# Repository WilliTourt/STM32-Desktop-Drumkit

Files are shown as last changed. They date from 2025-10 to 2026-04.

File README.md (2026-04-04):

# STM32 Desktop Drumkit

> **Language/语言**: [English](README.md) | [简体中文](README-zh-CN.md)

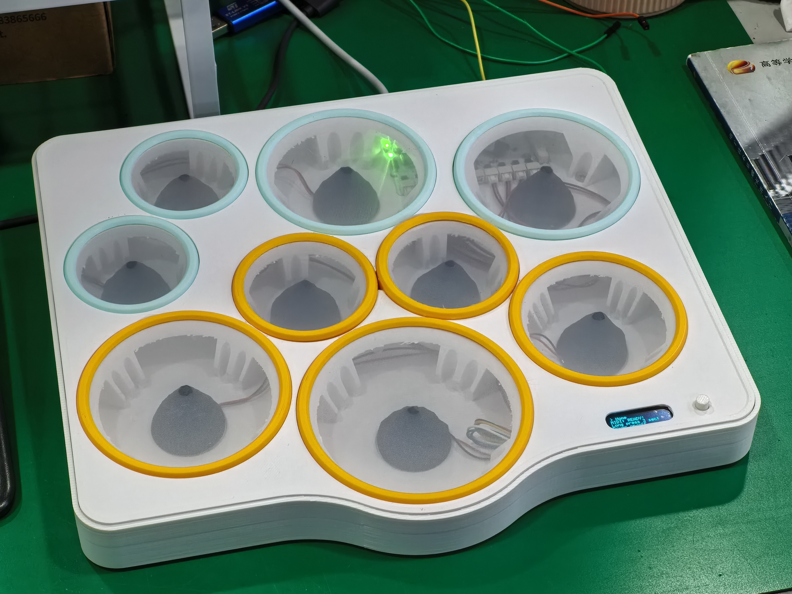
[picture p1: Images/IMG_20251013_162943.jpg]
Drumkit Image

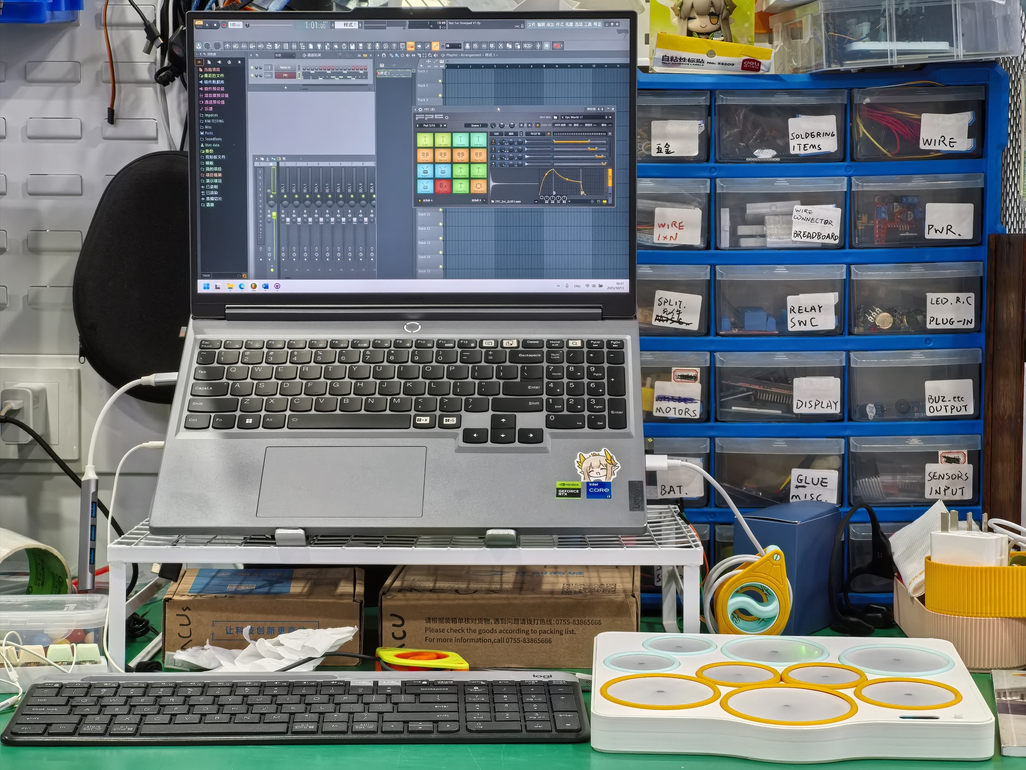
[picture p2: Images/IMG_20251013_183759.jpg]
Usage Example


## Project Overview

*Current Version: v1.0.3*

This project is an upgraded version of my previous ESP32 drum set. Here is its repository link: [ESP32 Desktop Drumkit v0 Prototype](https://github.com/WilliTourt/ESP32-Desktop-Drumkit-v0-Prototype)

STM32 Desktop Drumkit is a multifunctional electronic drumpad system based on STM32F4 microcontroller, supporting high-precision hit detection, native MIDI protocol output, real-time OLED status display, and multilevel menu human-machine interaction. The system includes 10 drum pads, using piezoelectric sensors and multi-channel ADC+DMA to achieve force detection, built-in customizable force curves (linear/logarithmic/exponential), threshold sensitivity adjustment, etc. It supports seamless connection with DAW, sound sources, electronic instruments, etc.

The project includes complete hardware schematics, PCB files, firmware code, debugging documents, assembly guides, etc. This README file provides independent document links for each section, making it easy to access.

Video demo: [Bilibili](https://www.bilibili.com/video/BV1LE4UzUE61/)

---

## Document Index

- [Hardware Design](Docs/hardware.md): Introduce the hardware design related to STM32 Desktop Drumkit, as well as the explanations related to PCB soldering and 3D part printing.
- [Software/Firmware/API Description](Docs/software.md)
- [Assembly Guide](Docs/partsassemble.md): A detailed illustrated guide on how to assemble STM32 Desktop Drumkit.
- [Debugging and Calibration Guide](Docs/howtodebug.md): This document guides you on how to calibrate parameters and conduct tests, etc.
- [FAQ](Docs/faq.md)

---

## Features

- **Multichannel drum pad detection**
- **High-speed ADC sampling and peak detection**
- **Customizable force mapping**
- **Standard MIDI signal transmission**
- **OLED status display and multilevel menu system**

---

## Quick Start

1. Refer to the [Hardware Description](Docs/hardware.md) for component procurement, PCB soldering, hardware circuit inspection and debugging, and 3D case printing.
2. Follow the [Assembly Guide](Docs/partsassemble.md) to complete hardware assembly. (Piezo sensor connection is also included in this step)
3. [Software/Firmware & API Description](Docs/software.md) Check this out, burn the firmware, connect the MIDI interface to the computer or other MIDI devices.
4. After powering on, press and hold the button to turn on the device, the OLED will display the welcome screen and enter the Home page.
5. Follow the [Debugging and Calibration Guide](Docs/howtodebug.md) to complete parameter calibration and testing.

---

## Hardware Description

- **Main Controller**: STM32F405RGT6
- **Piezoelectric Ceramic Disc**: Recommended 27mm, it is advised to use twisted pairs or shielded cables for each signal line.
- **ADC Sampling**: 12-bit precision, multiplexed
- **OLED Display**: 128x32 resolution, I2C interface
- **Others**: LEDs, buzzer, buttons, see the hardware schematic for peripheral interfaces.

---

## Source Code Structure

- `cpp_main.cpp/h` : Main program entry, main loop, Pad/MIDI/UI initialization and scheduling
- `pad.cpp/h` : Drum pad detection, force mapping, and parameter management
- `midi.cpp/h` : MIDI communication protocol, signal transmission, automatic Note Off, connection detection
- `oled.cpp/h` : OLED screen driver, text/variable/graphic display
- `OneButtonTiny.cpp/h` : Multimode input detection for a single button (single click/double click/long press/multi-click)
- `ui.cpp/h` : User interface and menu system management

---

## Changelog (Since 2025.10.14)

- [x] Complete documentation
- [x] Add config.h for parameter customization
- [x] Optimized knock recognition
- [x] Complete DebugLog feature

Below are undone features. Due to my limited time, this project is considered completed and will not be updated later

- [ ] Optimize UI interface
- [ ] Complete LED/BUZZER functionality
- [ ] Add PadTest feature
- [ ] Add PadSettings fine-tuning parameters
- [ ] SSTK sensor support
- [ ] Add 3D file of the base plate bracket
...

---

## Acknowledgments

- Thanks to [MoraiYanKele](https://github.com/MoraiYanKele) for providing his OLED multilevel menu library.
- Thanks to Matthias Hertel's Arduino Onebutton library, part of its functionality has been ported to this project.
- This project was initially inspired by [Victor2805/Homemade-electronic-drum-kit-with-arduino](https://github.com/Victor2805/Homemade-electronic-drum-kit-with-arduino).
- Thanks to my cousin who loves percussion instruments and is experienced with DAW, he provided many modification suggestions for the prototype @[Woodbreeze](https://github.com/WoodBreeze) ;)
- Thanks to all the authors of the open-source libraries and the DIY community for sharing their experiences.

---

**WilliTourt / 2025.10 V1 Release**

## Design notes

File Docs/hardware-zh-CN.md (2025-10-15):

# STM32 Desktop Drumkit - 硬件说明

> 此文档将会介绍STM32 Desktop Drumkit的硬件设计相关，以及PCB焊接和3D件打印相关说明。

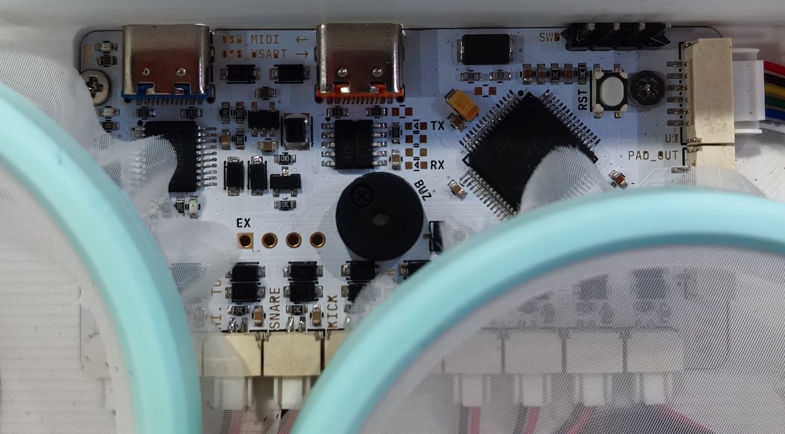
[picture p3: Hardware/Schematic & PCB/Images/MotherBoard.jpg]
主板PCB图

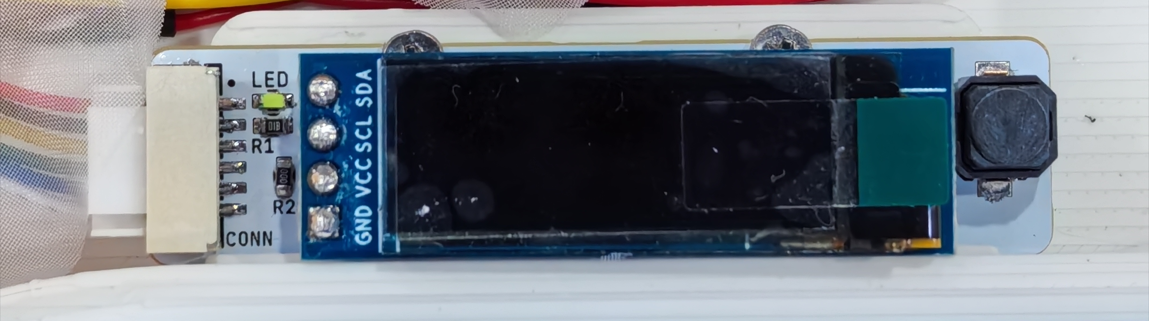
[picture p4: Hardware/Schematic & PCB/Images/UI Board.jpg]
UI小板PCB图

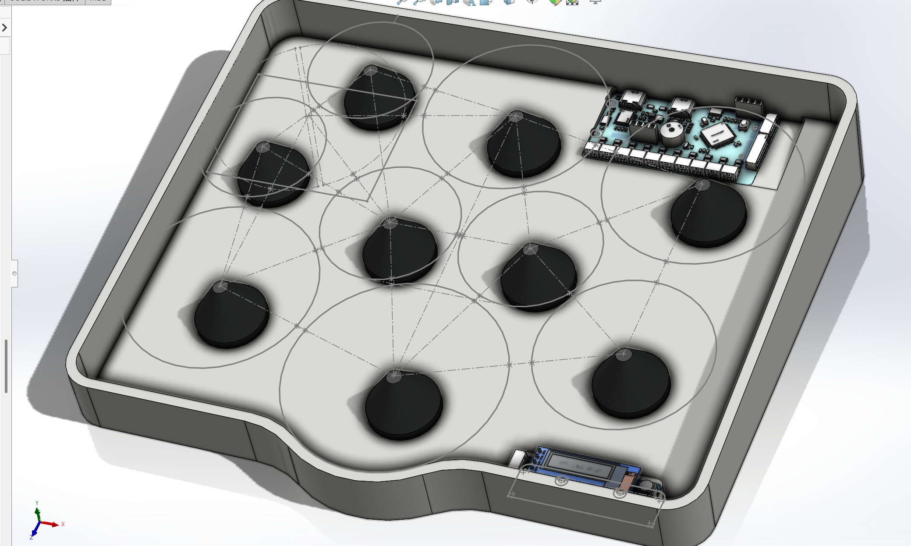
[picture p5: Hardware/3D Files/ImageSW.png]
3D外壳图


## PCB元器件清单

PCB所需元器件在[BOM文件夹](../Hardware/Schematic%20&%20PCB/PCB%20BOM)的表格中均已列出。PCB的设计文件和Gerber也在[原理图/PCB文件夹](../Hardware/Schematic%20&%20PCB)中。PCB包括两部分：主板和用户交互小板。

## PCB原理图说明

### 主板原理图
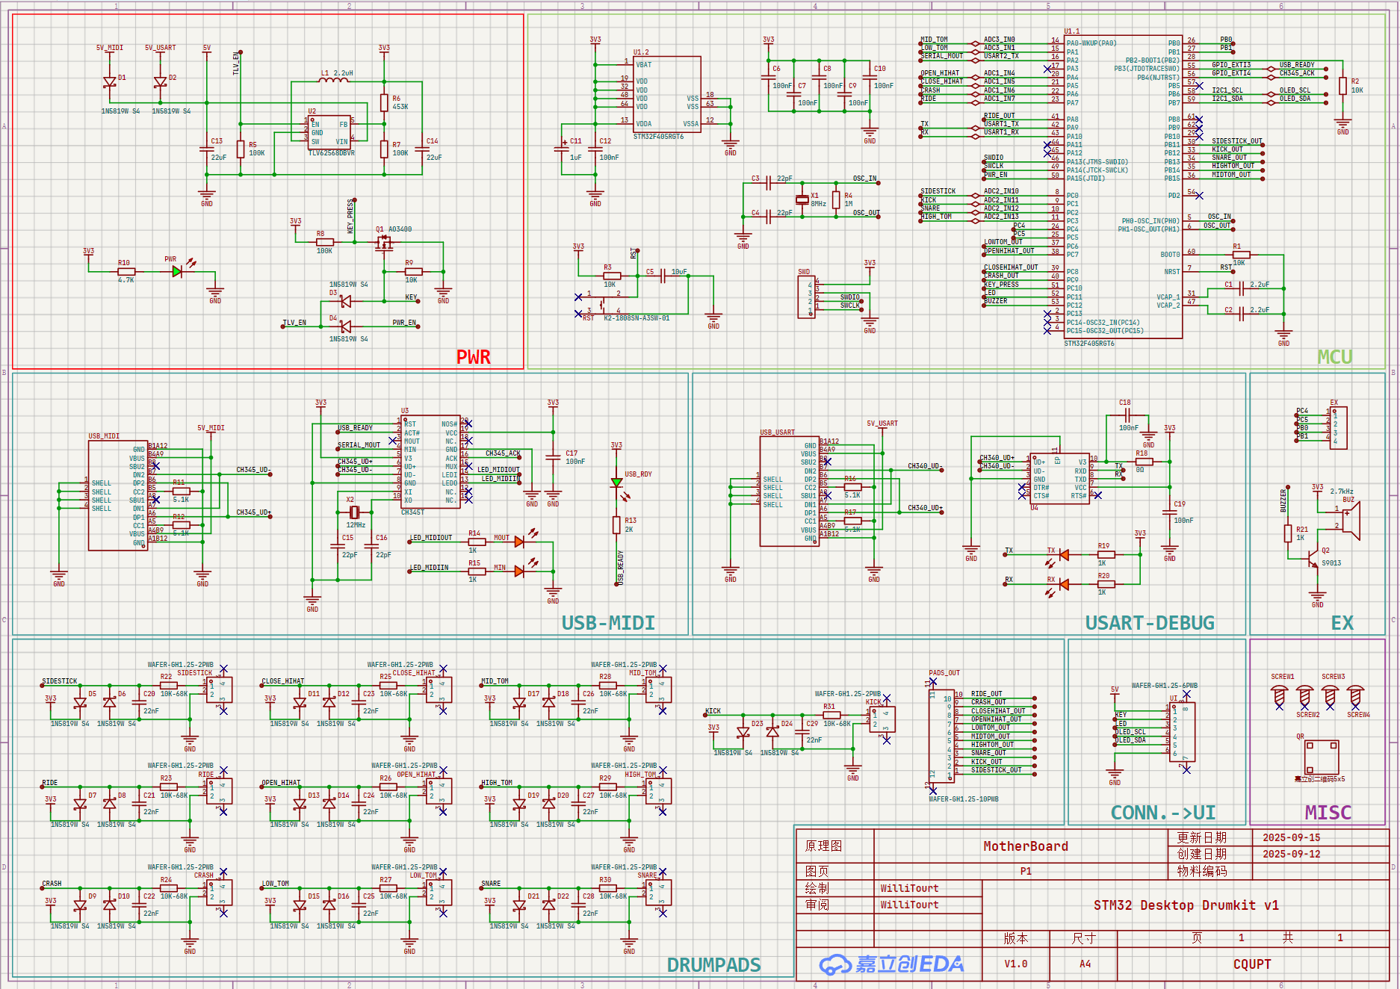
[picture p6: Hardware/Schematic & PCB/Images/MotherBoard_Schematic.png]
主板原理图


主板主要包括以下部分：
- MCU
- 电源
- 通信接口
- 压电片信号处理

信号输入输出流程：
1. 10路信号处理电路将外部压电片原信号进行偏置和限幅
2. 处理后的信号连接到MCU的ADC
3. MCU发送MIDI信息到CH345T USB-MIDI芯片
4. 发送调试信息到CH340K
5. 控制板载蜂鸣器
6. 通过6pin GH1.25接口：
   - 发送I2C数据到OLED
   - 控制LED
   - 接收按键输入

### 用户交互小板原理图
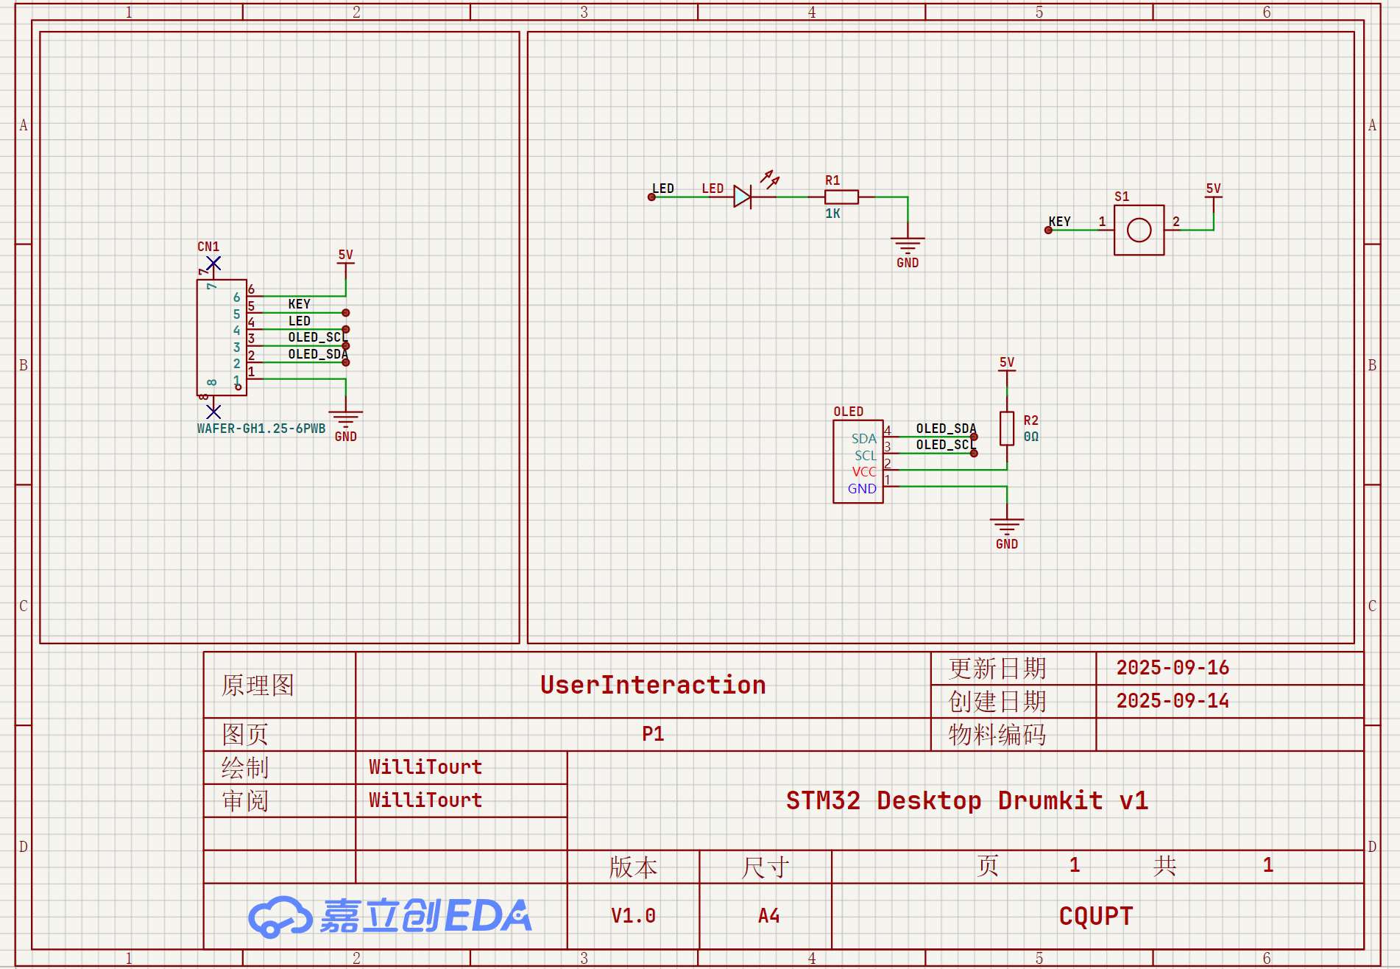
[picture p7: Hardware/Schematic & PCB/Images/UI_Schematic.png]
用户交互小板原理图


- 通过6pin接口接收来自MCU的数据
- MCU同时检测按键信号

## PCB布局

### 主板PCB布局
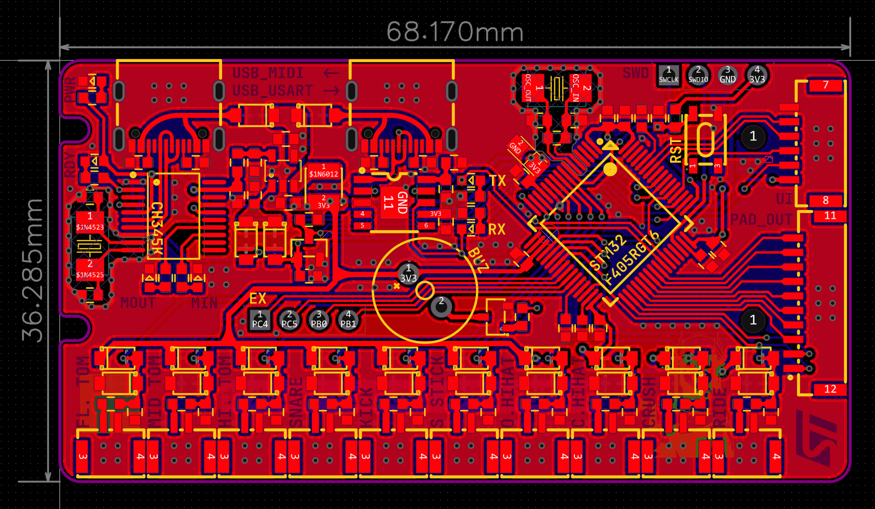
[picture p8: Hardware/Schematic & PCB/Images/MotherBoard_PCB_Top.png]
主板PCB布局


- 上方：三个接口
  - MIDI
  - UART_DEBUG
  - SWD
- 右侧：
  - 6pin用于连接UI小板的接口
  - 10pin输出控制接口
- 下方：10路独立的压电片信号处理电路
- 中部：
  - 电源选择电路
  - 开关机电路
  - DCDC降压器
  - MCU
  - 4个额外的IO

板上线路和STM32CubeMX配置相对应。使用CubeMX查看外设和引脚配置。

## PCB焊接注意事项

### 主板焊接注意事项
1. TLV62568的反馈电阻(100k/453k)切勿相互焊反
2. CH340K部分：
   - R18和C19焊接时请二选一
   - 推荐仅焊接R18以向V3引脚供3.3v电源（详细解释见CH340K数据手册）
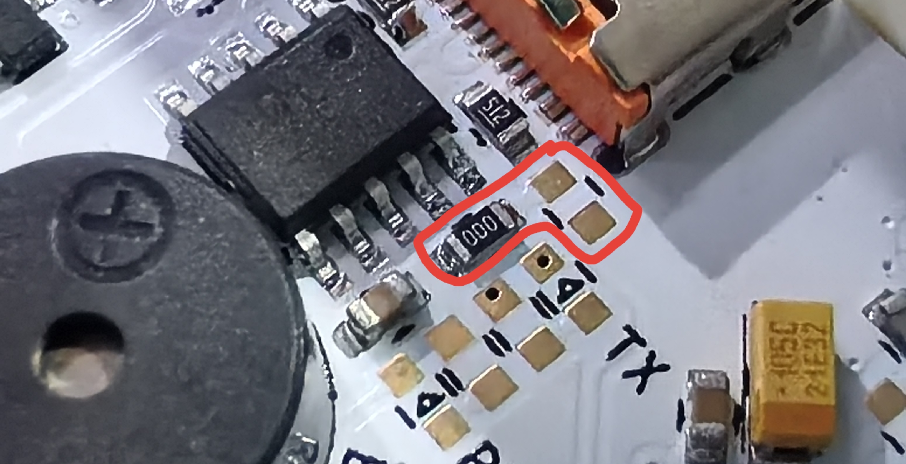
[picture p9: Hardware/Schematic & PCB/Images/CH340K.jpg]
CH340K
   
3. 注意信号处理电路的二极管方向
4. 信号处理电路的10k-68k电阻是限流电阻，推荐10k即可。
5. 所有用户LED都是可选的：
   - TX/RX指示灯
   - MIDI IN/OUT指示灯
   - MIDI USB_RDY
   - 3v3电源指示灯
6. MCU的晶振电路，1M电阻可不焊接

### UI小板焊接注意事项
1. OLED引脚插入深度：
   - 不要全部插入
   - 建议方法：
     - 等外壳打印好后
     - 将小板放置好
     - 将OLED插入，引脚刚好触即外壳缺口底部即可（稍后的[组装指南](Docs/partsassemble-zh-CN.md)中有提及）

## 3D 打印

所有相关的3D文件均在[3D Files文件夹](../Hardware/3D%20Files)中。一共需要打印这些部分：
- 外壳 ([Desktop Drumkit V1.0.step](../Hardware/3D%20Files/step%20&%203mf/Desktop%20Drumkit%20V1.0.STEP))
- 顶板 ([Drumkit Cover.step](../Hardware/3D%20Files/step%20&%203mf/Drumkit%20Cover.STEP))
- 叮叮镲支架 ([DrumpadStand_Ride.step](../Hardware/3D%20Files/step%20&%203mf/DrumpadStand_Ride.STEP))
- 7种不同大小的鼓皮紧固环 ([Fasteners 文件夹](../Hardware/3D%20Files/step%20&%203mf/Fasteners))，其中踩镲和高嗵鼓的环需要打印两个。

### 3D打印设置

如果你使用Bambu Studio，则可以直接使用我上传的3mf项目文件，切片选项已全部配置好（但注意切换打印机和打印板选项）。但外壳主体的3mf未能上传（因文件大小大于100M）

如果你使用其他3D打印软件，则需主要关注以下设置：
- 外壳：
  - 支撑：底部槽口无需添加支撑，**上方紧固圈部分需全部添加支撑！!**
  - 顶部壳体厚度：至少**1.6mm**，越厚越好。需要保证之后组装时用力按压紧固环时的结构完整性。
  - 稀疏填充：请不要低于12%
  - 速度：建议稍慢一些

- 紧固环
  - 墙层数：请直接塞满整个环

- 顶板
  - 顶板模型含有很薄的墙，注意放慢速度！！同时可以尝试Arachne墙生成

- 叮叮镲支架
  - 正常打印即可，无需特殊设置。

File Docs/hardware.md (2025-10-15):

# STM32 Desktop Drumkit - Hardware Description

> This document will introduce the hardware design related to STM32 Desktop Drumkit, as well as the explanations related to PCB soldering and 3D part printing.

Main Board PCB
UI Board PCB
3D Case

## PCB Components List

All required components for the PCB are listed in the BOM tables in the [BOM folder](../Hardware/Schematic%20&%20PCB/PCB%20BOM). The design files and Gerber files are also available in the [Schematic/PCB folder](../Hardware/Schematic%20&%20PCB). The PCB consists of two parts: the main board and the user interface small board.

## PCB Schematic Description

### Main Board Schematic
Main Board Schematic

The main board includes the following parts:
- MCU
- Power supply
- Communication interfaces
- Piezo sensor signal processing

Signal input/output flow:
1. 10-channel signal processing circuits perform biasing and clipping on the raw signals from external piezo sensors
2. Processed signals are connected to the MCU's ADC
3. MCU sends MIDI messages to the CH345T USB-MIDI chip
4. Sends debug information to CH340K
5. Controls the onboard buzzer
6. Through 6pin GH1.25 interface:
   - Sends I2C data to OLED
   - Controls LEDs
   - Receives button inputs

The connection layout are corresponding to STM32CubeMX configuration. Use CubeMX to see peripherals and pin configuration.

### User Interface Small Board Schematic
User Interface Small Board Schematic

- Receives data from MCU through 6pin interface
- MCU also detects button signals

## PCB Layout

### Main Board PCB Layout
Main Board PCB Layout

- Top: Three interfaces
  - MIDI
  - UART_DEBUG
  - SWD
- Right side:
  - 6pin interface for connecting UI small board
  - 10pin output control interface
- Bottom: 10 independent piezo sensor signal processing circuits
- Center:
  - Power selection circuit
  - Power toggle circuit
  - DCDC buck converter
  - MCU
  - 4 extra IOs

## PCB Soldering Notes

### Main Board
1. Feedback resistors for TLV62568 (100k/453k) must not be swapped
2. CH340K section:
   - R18 and C19 should be soldered as alternatives (choose one only)
   - Recommended to solder only R18 to supply 3.3v power to V3 pin (see CH340K datasheet for details)
   CH340K
3. Pay attention to diode direction in signal processing circuits
4. The 10k-68k resistors in the signal processing circuit are current-limiting resistors, 10k is recommended.
5. All user LEDs are optional:
   - TX/RX indicators
   - MIDI IN/OUT indicators
   - MIDI USB_RDY
   - 3v3 power indicator
6. For MCU crystal circuit, the 1M resistor can be left unsoldered

### UI Board
1. OLED pin insertion depth:
   - Do not insert fully
   - Recommended method:
     - After the case is printed
     - Place the small board in position
     - Insert OLED so pins just touch the bottom of the case notch (noticed in [Assembly Guide](Docs/partsassemble.md))

## 3D Printing

All related 3D files are in the [3D Files folder](../Hardware/3D%20Files). The following parts need to be printed:
- Case ([Desktop Drumkit V1.0.step](../Hardware/3D%20Files/step%20&%203mf/Desktop%20Drumkit%20V1.0.STEP))
- Top cover ([Drumkit Cover.step](../Hardware/3D%20Files/step%20&%203mf/Drumkit%20Cover.STEP))
- Ride cymbal stand ([DrumpadStand_Ride.step](../Hardware/3D%20Files/step%20&%203mf/DrumpadStand_Ride.STEP))
- 7 different sizes of drumhead fasteners ([Fasteners folder](../Hardware/3D%20Files/step%20&%203mf/Fasteners)), among which the hi-hat and high tom fasteners need to be printed twice.

### 3D Printing Settings

If you use Bambu Studio, you can directly use the 3mf project files I uploaded, with all slicing options pre-configured (but pay attention to switching printer and print bed options). However, the main case 3mf file was not uploaded (because the file size exceeds 100M).

If you use other 3D printing software, please pay attention to the following settings:
- Case:
  - Supports: No need to add supports for the bottom slots, **but full supports are required for the upper fastener ring parts!!**
  - Top shell thickness: At least **1.6mm**, the thicker the better. This ensures structural integrity when pressing the fasteners during assembly.
  - Sparse infill: Not lower than 12%
  - Speed: Recommended to be slightly slower

- Fasteners
  - Wall count: Fill the entire ring directly

- Top cover
  - The top cover model has very thin walls, slow down the printing speed!! You can also try Arachne wall generation.

- Ride cymbal stand
  - Normal printing, no special settings required.

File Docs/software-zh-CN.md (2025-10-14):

# STM32 Desktop Drumkit - 软件/固件/API 文档

## 系统概述

STM32 Desktop Drumkit是一个将鼓垫敲击转换为 MIDI 消息的控制器，具有以下特点：

- 10 个带力度感应的鼓垫输入
- OLED 显示屏用于状态显示和配置
- USB MIDI 输出
- 可配置的鼓垫设置

## 硬件接口

### 引脚配置

MIDI 音符配置可以在 midi.h 中轻松修改。详见[调试与参数标定](Docs/howtodebug-zh-CN.md)。

| 鼓垫名称 | ADC 组 | ADC 通道 | 输出端口/引脚 | MIDI 音符 |
|---|---|---|---|---|
| 开踩镲 | ADC1 | 0 | GPIOA/P4 | 46 |
| 闭踩镲 | ADC1 | 1 | GPIOA/P5 | 42 |
| 吊镲 | ADC1 | 2 | GPIOA/P6 | 49 |
| 叮叮镲 | ADC1 | 3 | GPIOA/P7 | 51 |
| 边击 | ADC2 | 0 | GPIOC/P0 | 37 |
| 底鼓 | ADC2 | 1 | GPIOC/P1 | 35 |
| 军鼓 | ADC2 | 2 | GPIOC/P2 | 38 |
| 中通鼓 | ADC3 | 0 | GPIOA/P0 | 48 |
| 低通鼓 | ADC3 | 1 | GPIOA/P1 | 45 |
| 高通鼓 | ADC3 | 2 | GPIOC/P3 | 50 |

### 外设使用

- **ADC1-3**: 鼓垫输入检测(使用 DMA)
- **I2C1**: OLED 显示屏通信
- **USART1**: 调试输出
- **USART2**: MIDI 输出
- **GPIO**: 鼓垫输出触发、按钮、LED

## 软件架构

本项目采用模块化设计，使用 C++ 而非 C 以便更好地处理多个类实例。主入口点为 `cpp_main.cpp`。
本项目使用VSCode + EIDE插件编写，如果你也使用EIDE，可以直接导入workspace。

### 主要组件

1. **Pad 类** (`pad.h/cpp`)
   - 处理鼓垫输入
   - 敲击检测和力度测量
   - 力度映射曲线

2. **UI 类** (`ui.h/cpp`)
   - OLED 显示管理
   - 菜单导航
   - 按钮输入处理

3. **Midi 类** (`midi.h/cpp`)
   - MIDI 消息构造
   - Note On/Off 处理
   - 通道状态管理

4. **主应用** (`cpp_main.cpp`)
   - 系统初始化
   - 主处理循环
   - 模块协调

### 数据流

1. 通过 ADC/DMA 检测鼓垫敲击
2. 测量力度值并映射为速度
3. 发送 MIDI Note On 消息
4. 更新 UI 显示鼓垫活动
5. 一定时间后自动发送 MIDI Note Off

## API 参考

### Pad 类

```cpp
class Pad {
public:
    // ADC 组(1-3)
    enum ADCGroup { ADC_1, ADC_2, ADC_3 };
    
    // 鼓垫标识(共10个鼓垫)
    enum PadID { OpenHiHat, CloseHiHat, Crash, Ride, SideStick, 
                Kick, Snare, MidTom, LowTom, HighTom, PAD_NUM };
    
    // 力度映射曲线(线性/对数/指数)
    enum ForceMappingCurve { CURVE_LINEAR, CURVE_LOG, CURVE_EXP };
    
    // 构造函数: 配置鼓垫参数
    // 参数说明: ADC组、ADC序号、输出端口/引脚、鼓垫ID、触发阈值、力度上限、映射曲线类型
    Pad(ADCGroup group, uint8_t adc_index, GPIO_TypeDef* port, uint16_t pin, 
        PadID id, uint16_t threshold, uint16_t upper_limit, ForceMappingCurve curve);
        
    // 核心功能:
    void detectHit();      // 检测新敲击(首先调用)
    bool isTriggered();    // 检查是否有新敲击
    void measureForce();   // 触发后计算力度
    uint8_t getForce();    // 获取力度值(0-127)
    
    // 实用功能:
    PadID getID();        // 获取鼓垫标识
    void setForceCurve(ForceMappingCurve curve); // 更改映射曲线
    uint16_t getADCVal_DBG(); // 获取原始ADC值(仅调试)
};
```

### UI 类

```cpp 
class UI {
public:
    // 显示模式(实时页面/菜单导航)
    enum class DisplayMode { PAGE, MENU };
    
    // 可用页面(主页面/测试页/设置页/统计页)
    enum class Page { MAIN, PAD_TEST, PAD_SETTING, STATS };
    
    // 初始化UI和按钮时序参数
    void init();
    void buttonInit(uint16_t debounce, uint16_t click_ms, uint16_t press_ms, uint16_t multi_ms);
    
    // 运行时功能(在主循环中调用):
    void buttonTick();    // 处理按钮输入
    void update();        // 刷新显示
    
    // 状态更新:
    void updatePadStats(Pad::PadID id, uint32_t hits); // 更新敲击计数
    void updateMidiStats();  // 更新MIDI统计
    void updateMidiConn(bool connected); // 更新连接状态
    
    // 显示控制:
    void setMode(DisplayMode mode); // 切换PAGE/MENU模式
    void setPage(Page page);       // 更改显示页面
    DisplayMode getMode();         // 获取当前模式
    Page getPage();                // 获取当前页面
};
```

### Midi 类

```cpp
class Midi {
public:
    // 发送MIDI消息:
    bool sendNoteOn(Pad::PadID padID, uint8_t velocity, uint8_t channel = 10);
    void sendNoteOff(Pad::PadID padID); // 自动使用鼓垫的音符/通道
    void sendNoteOff(uint8_t note, uint8_t channel = 10); // 手动音符关闭
    
    // 处理自动Note Off(在主循环中调用)
    void autoNoteOff();
    
    // 检查连接状态
    bool isConnected();
};
```

## 固件

可以使用 STM32CubeProgrammer 或者 STM32 Utility 工具烧写固件。
固件文件已编译好，在 Project folder/build 目录下。

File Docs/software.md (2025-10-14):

# STM32 Desktop Drumkit - Software/Firmware/API Documentation

## System Overview

The STM32 Desktop Drumkit is a MIDI controller that converts drum pad hits into MIDI messages. It features:

- 10 drum pads with velocity-sensitive input
- OLED display for status and configuration
- USB MIDI output
- Configurable pad settings

## Hardware Interfaces

### Pin Configuration

The midi note config can be easily modified in midi.h if u want. See [Debugging & Parameter Calibration](Docs/howtodebug.md) for details.

| Pad Name | ADC Group | ADC Channel | Output Port/Pin | MIDI Note |
|---|---|---|---|---|
| OpenHiHat | ADC1 | 0 | GPIOA/P4 | 46 |
| CloseHiHat  | ADC1 | 1 | GPIOA/P5 | 42 |
| Crash | ADC1 | 2 | GPIOA/P6 | 49 |
| Ride | ADC1 | 3 | GPIOA/P7 | 51 |
| SideStick | ADC2 | 0 | GPIOC/P0 | 37 |
| Kick | ADC2 | 1 | GPIOC/P1 | 35 |
| Snare | ADC2 | 2 | GPIOC/P2 | 38 |
| MidTom | ADC3 | 0 | GPIOA/P0 | 48 |
| LowTom | ADC3 | 1 | GPIOA/P1 | 45 |
| HighTom | ADC3 | 2 | GPIOC/P3 | 50 |

### Peripheral Usage

- **ADC1-3**: Pad input sensing (with DMA)
- **I2C1**: OLED display communication  
- **USART1**: Debug output
- **USART2**: MIDI output
- **GPIO**: Pad output triggers, buttons, LEDs

## Software Architecture

This project is designed to be modular. I chose to use C++ instead of C to better handle multiple insts of classes. The main entry point is `cpp_main.cpp`.
This project is developed using VSCode with EIDE plugin. If you also use EIDE, you can directly import the workspace.

### Main Components

1. **Pad Class** (`pad.h/cpp`)
   - Handles pad input processing
   - Hit detection and force measurement
   - Velocity mapping curves

2. **UI Class** (`ui.h/cpp`)
   - OLED display management
   - Menu navigation
   - Button input handling

3. **Midi Class** (`midi.h/cpp`)
   - MIDI message construction
   - Note On/Off handling
   - Channel state management

4. **Main Application** (`cpp_main.cpp`)
   - System initialization
   - Main processing loop
   - Module coordination

### Data Flow

1. Pad hits are detected via ADC/DMA
2. Force values are measured and mapped to velocity
3. MIDI Note On messages are sent
4. UI is updated with pad activity
5. MIDI Note Off is sent automatically after a certain period of time

## API Reference

### Pad Class

```cpp
class Pad {
public:
    // ADC groups (1-3)
    enum ADCGroup { ADC_1, ADC_2, ADC_3 };
    
    // Pad identifiers (10 pads total)
    enum PadID { OpenHiHat, CloseHiHat, Crash, Ride, SideStick, 
                Kick, Snare, MidTom, LowTom, HighTom, PAD_NUM };
    
    // Force mapping curves (linear/log/exp)
    enum ForceMappingCurve { CURVE_LINEAR, CURVE_LOG, CURVE_EXP };
    
    // Constructor: configures pad with ADC, GPIO and response settings
    // Pad parameters: ADC group, adc rank, output port/pin, ID, trigger threshold, limit, mapping curve type
    Pad(ADCGroup group, uint8_t adc_index, GPIO_TypeDef* port, uint16_t pin, 
        PadID id, uint16_t threshold, uint16_t upper_limit, ForceMappingCurve curve);
        
    // Core pad functions:
    void detectHit();      // Detect new hits (call first)
    bool isTriggered();    // Check if new hit detected
    void measureForce();   // Calculate force after trigger
    uint8_t getForce();    // Get velocity value (0-127)
    
    // Utility functions:
    PadID getID();        // Get pad identifier
    void setForceCurve(ForceMappingCurve curve); // Change mapping curve
    uint16_t getADCVal_DBG(); // Get raw ADC value (debug only)
};
```

### UI Class

```cpp 
class UI {
public:
    // Display modes (PAGE for real-time, MENU for navigation)
    enum class DisplayMode { PAGE, MENU };
    
    // Available pages (main, test, settings, stats)
    enum class Page { MAIN, PAD_TEST, PAD_SETTING, STATS };
    
    // Initialize UI and button with timing parameters
    void init();
    void buttonInit(uint16_t debounce, uint16_t click_ms, uint16_t press_ms, uint16_t multi_ms);
    
    // Runtime functions (call in main loop):
    void buttonTick();    // Process button input
    void update();        // Refresh display
    
    // Status updates:
    void updatePadStats(Pad::PadID id, uint32_t hits); // Update hit counts
    void updateMidiStats();  // Update MIDI stats
    void updateMidiConn(bool connected); // Update connection status
    
    // Display control:
    void setMode(DisplayMode mode); // Switch between PAGE/MENU
    void setPage(Page page);       // Change display page
    DisplayMode getMode();         // Get current mode
    Page getPage();                // Get current page
};
```

### Midi Class

```cpp
class Midi {
public:
    // Send MIDI messages:
    bool sendNoteOn(Pad::PadID padID, uint8_t velocity, uint8_t channel = 10);
    void sendNoteOff(Pad::PadID padID); // Auto uses pad's note/channel
    void sendNoteOff(uint8_t note, uint8_t channel = 10); // Manual note off
    
    // Handle automatic note off (call in main loop)
    void autoNoteOff();
    
    // Check connection status
    bool isConnected();
};
```

## Firmware

You can use STM32CubeProgrammer or STM32 Utility tools to flash the firmware.
Pre-built firmware files are available in the Project folder/build directory.

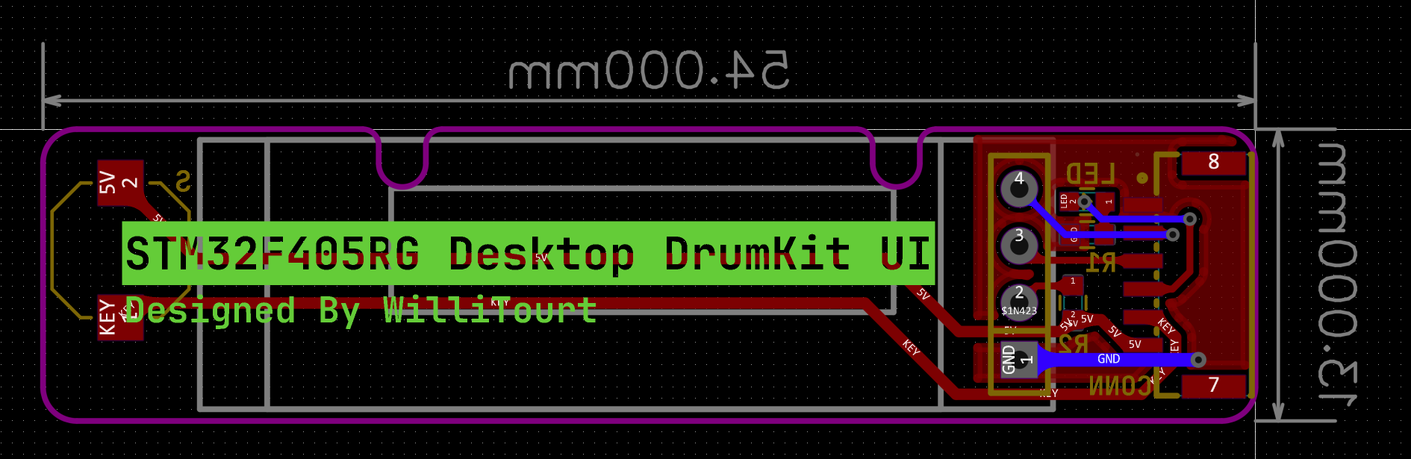
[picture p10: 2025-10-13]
Hardware/Schematic & PCB/Images/UI_PCB_Bottom.png

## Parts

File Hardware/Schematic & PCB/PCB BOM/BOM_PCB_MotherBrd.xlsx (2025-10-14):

No. | Quantity | Comment | Designator | Footprint | Value | Manufacturer Part | Manufacturer | Supplier Part | Supplier
1 | 1 | 2.7kHz | BUZ | BUZ-TH_BD9.0-P4.00-D0.6-FD | 2.7kHz | QMB-09B-03 | 华能 | C96256 | LCSC
2 | 2 | 2.2uF | C1,C2 | C0603 | 2.2uF
3 | 4 | 22pF | C3,C4,C15,C16 | C0603 | 22pF
4 | 1 | 10uF | C5 | C0603 | 10uF
5 | 9 | 100nF | C6,C7,C8,C9,C10,C12,C17,C18,C19 | C0603 | 100nF
6 | 1 | 1uF | C11 | CASE-A_3216 | 1uF | TAJA105K016RNJ | Kyocera AVX | C7174 | LCSC
7 | 2 | 22uF | C13,C14 | C0603 | 22uF
8 | 10 | 22nF | C20,C21,C22,C23,C24,C25,C26,C27,C28,C29 | C0603 | 22nF
9 | 10 | WAFER-GH1.25-2PWB | C.HIHAT,CRUSH,FL. TOM,HI. TOM,KICK,MID TOM,O.HIHAT,RIDE,S STICK,SNARE | CONN-TH_2P-P1.25_XUNPU_WAFER-GH1.25-2PWB |  | WAFER-GH1.25-2PWB | XUNPU(讯普) | C3029377 | LCSC
10 | 1 | CH345T | CH345K | SSOP-20_L7.2-W5.3-P0.65-LS7.8-BL |  | CH345T | WCH(南京沁恒) | C5246448 | LCSC
11 | 24 | 1N5819W S4 | D1,D2,D3,D4,D5,D6,D7,D8,D9,D10,D11,D12,D13,D14,D15,D16,D17,D18,D19,D20,D21,D22,D23,D24 | SOD-123_L2.7-W1.6-LS3.7-RD |  | 1N5819W S4 | TDSEMIC(拓电半导体) | C42441798 | LCSC
12 | 2 | HDR-F_2.54_1x4P | EX,SWD | HDR-TH_4P-P2.54-V-F |  |  |  | C2718488
13 | 1 | 2.2uH | L1 | IND-SMD_L3.0-W3.0_FNR30XXS | 2.2uH | FNR3015S2R2MT | cjiang(长江微电) | C167747 | LCSC
14 | 4 | LED0603-ORANGE | MIN,MOUT,RX,TX | LED0603
15 | 1 | WAFER-GH1.25-10PWB | PAD_OUT | CONN-SMD_10P-P1.25_XUNPU_WAFER-GH1.25-10PWB |  | WAFER-GH1.25-10PWB | XUNPU(讯普) | C3029385 | LCSC
16 | 2 | LED0603-GREEN | PWR,RDY | LED0603
17 | 1 | AO3400 | Q1 | SOT-23-3_L2.9-W1.3-P1.90-LS2.4-BR |  | AO3400 | Hottech(合科泰) | C181090 | LCSC
18 | 1 | S9013 | Q2 | SOT-23-3_L2.9-W1.4-P1.90-LS2.6-BR |  | S9013 | CBI(创基) | C2836092 | LCSC
19 | 4 | 10K | R1,R2,R3,R9 | R0603 | 10K
20 | 1 | 1M | R4 | R0603 | 1M
21 | 3 | 100K | R5,R7,R8 | R0603 | 100K
22 | 1 | 453K | R6 | R0603 | 453K
23 | 1 | 4.7K | R10 | R0603 | 4.7K
24 | 4 | 5.1K | R11,R12,R16,R17 | R0603 | 5.1K
25 | 1 | 2K | R13 | R0603 | 2K
26 | 5 | 1K | R14,R15,R19,R20,R21 | R0603 | 1K
27 | 1 | 0Ω | R18 | R0603 | 0Ω
28 | 10 | 10K-68K | R22,R23,R24,R25,R26,R27,R28,R29,R30,R31 | R0603 | 10K-68K
29 | 1 | K2-1808SN-A3SW-01 | RST | SW-SMD_4P-L4.2-W3.3-P2.15-LS5.1 |  | K2-1808SN-A3SW-01 | 韩国韩荣 | C2690012 | LCSC
30 | 1 | STM32F405RGT6 | STM32F405RGT6 | NaN |  | STM32F405RGT6 | ST(意法半导体) | C15742 | LCSC
31 | 1 | TLV62568DBVR | U2 | SOT-23-5_L3.0-W1.7-P0.95-LS2.8-BR |  | TLV62568DBVR | TI(德州仪器) | C163219 | LCSC
32 | 1 | CH340K | U4 | ESOP-10_L4.9-W3.9-P1.00-LS6.2-BL-EP |  | CH340K | WCH(南京沁恒) | C968586 | LCSC
33 | 1 | WAFER-GH1.25-6PWB | UI | CONN-SMD_6P-P1.25_XUNPU_WAFER-GH1.25-6PWB |  | WAFER-GH1.25-6PWB | XUNPU(讯普) | C3029381 | LCSC
34 | 2 | Type-C-TOP_1 | USB_MIDI <-,USB_USART -> | USB-C-SMD_TYPE-C16PIN |  |  |  | C9900005857 | LCSC
35 | 1 | 8MHz | X1 | CRYSTAL-SMD_L5.0-W3.2 | 8MHz | X50328MSB2GI | YXC(扬兴晶振) | C115962 | LCSC
36 | 1 | 12MHz | X2 | OSC-SMD_L5.0-W3.2 | 12MHz | X503212MSB2GI | YXC(扬兴晶振) | C112573 | LCSC

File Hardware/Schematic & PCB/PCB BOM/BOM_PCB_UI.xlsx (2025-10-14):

No. | Quantity | Comment | Designator | Footprint | Value | Manufacturer Part | Manufacturer | Supplier Part | Supplier
1 | 1 | WAFER-GH1.25-6PWB | CONN | CONN-SMD_6P-P1.25_XUNPU_WAFER-GH1.25-6PWB |  | WAFER-GH1.25-6PWB | XUNPU(讯普) | C3029381 | LCSC
2 | 1 | LED0603-WHITE | LED | LED0603
3 | 1 | OLED-0.91-12832-I2C-SSD1306 | OLED | MOULD-OLED-0.91-12832-I2C-SSD1306
4 | 1 | 1K | R1 | R0603 | 1K
5 | 1 | 0Ω | R2 | R0603 | 0Ω
6 | 1 | 6*6*5 硅胶开关 Switch | S | 6*6*5 硅胶开关 Switch

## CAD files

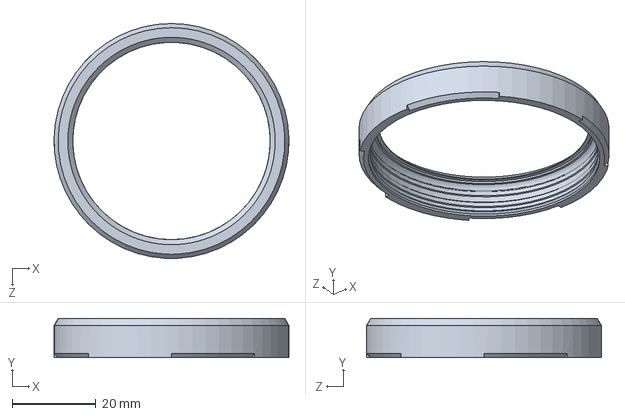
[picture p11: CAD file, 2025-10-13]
Hardware/3D Files/SolidWorks/DrumpadFastener Hi_Mid_Tom 56.SLDPRT
56.0 x 9.40 x 56.0 mm

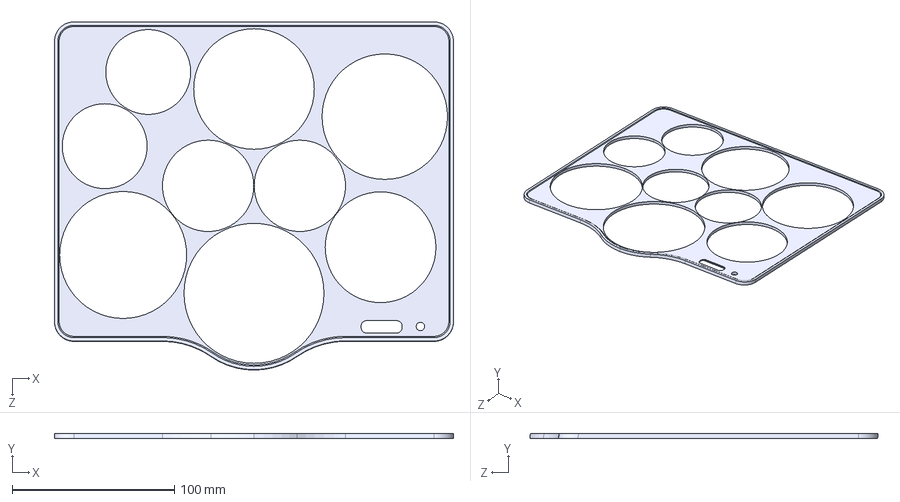
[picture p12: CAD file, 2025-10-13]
Hardware/3D Files/step & 3mf/Drumkit Cover.STEP
245.9 x 3.00 x 214.5 mm

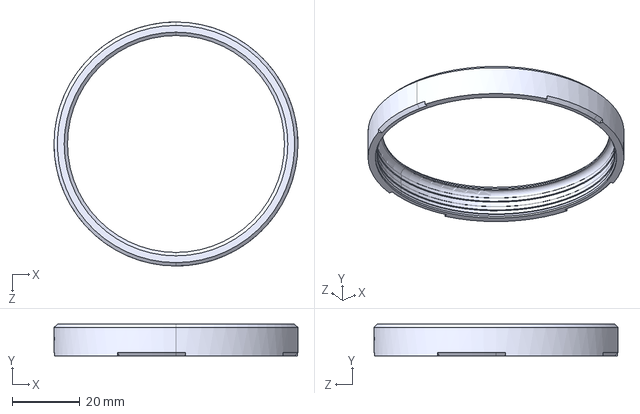
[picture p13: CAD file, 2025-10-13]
Hardware/3D Files/step & 3mf/Tests/DrumpadTest_Fastener_2.STEP
72.0 x 9.40 x 72.0 mm

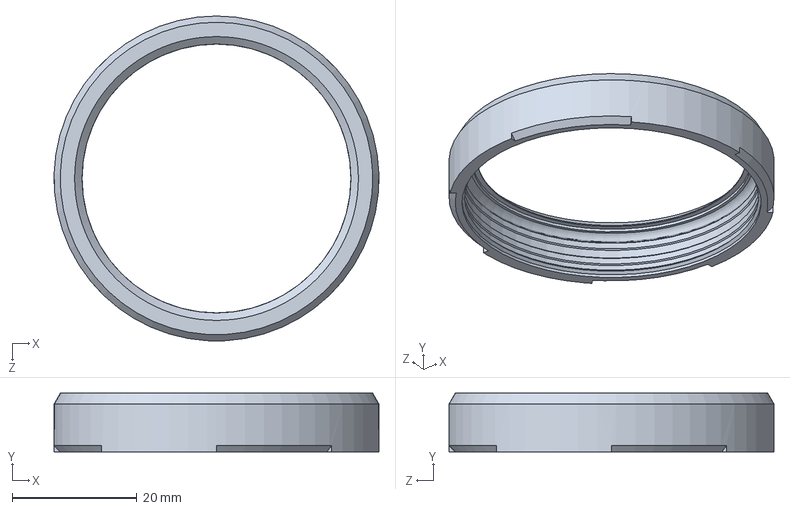
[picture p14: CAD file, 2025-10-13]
Hardware/3D Files/SolidWorks/DrumpadFastener Hihat 52.SLDPRT
52.0 x 9.40 x 52.0 mm

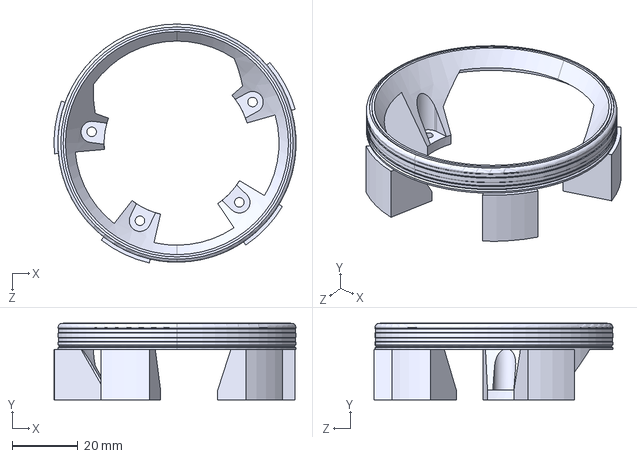
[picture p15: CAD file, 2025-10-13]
Hardware/3D Files/step & 3mf/DrumpadStand_Ride.STEP
73.8 x 23.4 x 72.8 mm

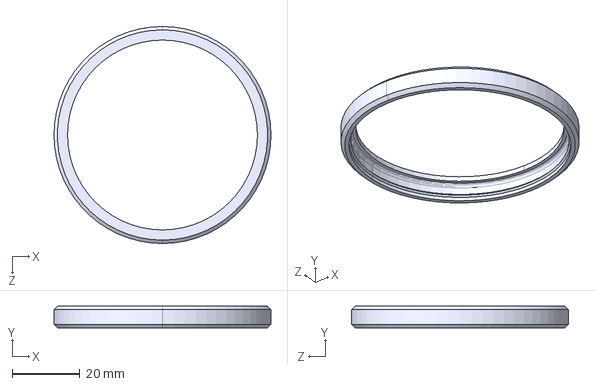
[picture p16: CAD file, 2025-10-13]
Hardware/3D Files/step & 3mf/Tests/DrumpadTest_Fastener_1.STEP
64.0 x 6.40 x 64.0 mm

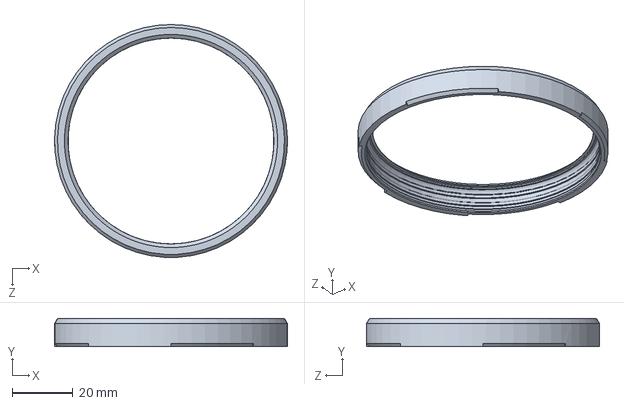
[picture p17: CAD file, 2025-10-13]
Hardware/3D Files/SolidWorks/DrumpadFastener Ride 77.SLDPRT
77.0 x 9.40 x 77.0 mm

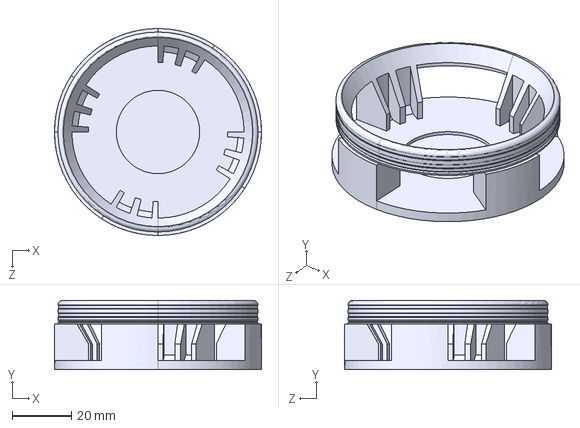
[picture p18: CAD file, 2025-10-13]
Hardware/3D Files/step & 3mf/Tests/DrumpadTest_2.STEP
70.0 x 23.4 x 70.0 mm

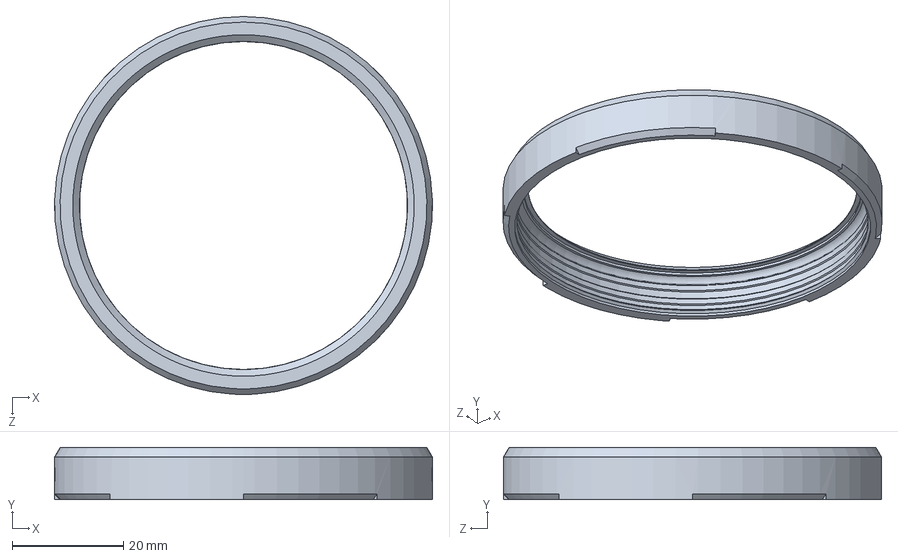
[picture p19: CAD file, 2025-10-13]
Hardware/3D Files/SolidWorks/DrumpadFastener LowTom 68.SLDPRT
68.0 x 9.40 x 68.0 mm

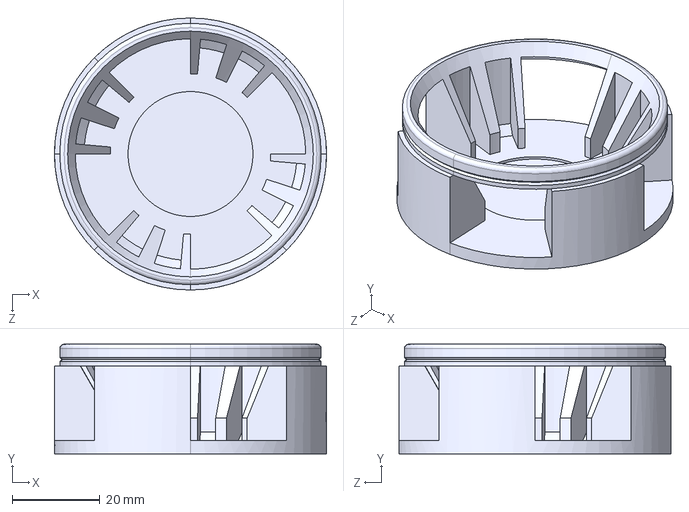
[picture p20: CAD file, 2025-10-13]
Hardware/3D Files/step & 3mf/Tests/DrumpadTest_1.STEP
62.0 x 25.0 x 62.0 mm

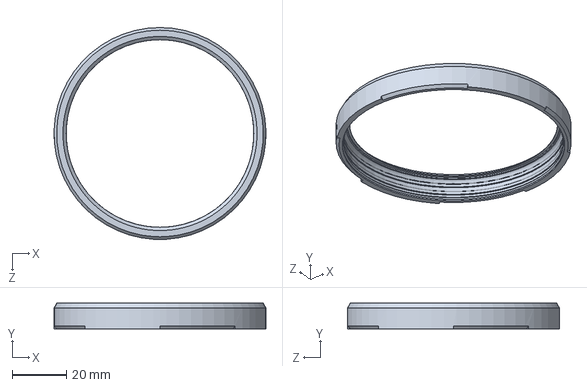
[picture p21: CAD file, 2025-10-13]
Hardware/3D Files/SolidWorks/DrumpadFastener Snare 78.SLDPRT
78.0 x 9.40 x 78.0 mm

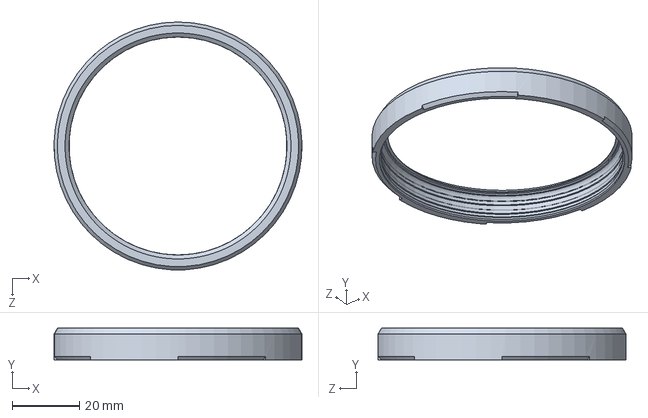
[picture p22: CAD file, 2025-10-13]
Hardware/3D Files/SolidWorks/DrumpadFastener Crash 74.SLDPRT
74.0 x 9.40 x 74.0 mm

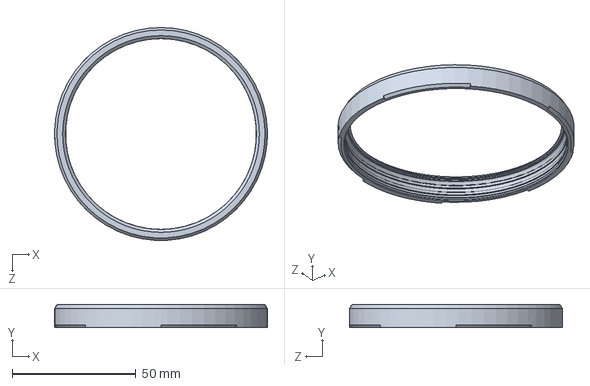
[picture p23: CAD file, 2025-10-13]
Hardware/3D Files/SolidWorks/DrumpadFastener Kick 86.SLDPRT
86.0 x 9.40 x 86.0 mm

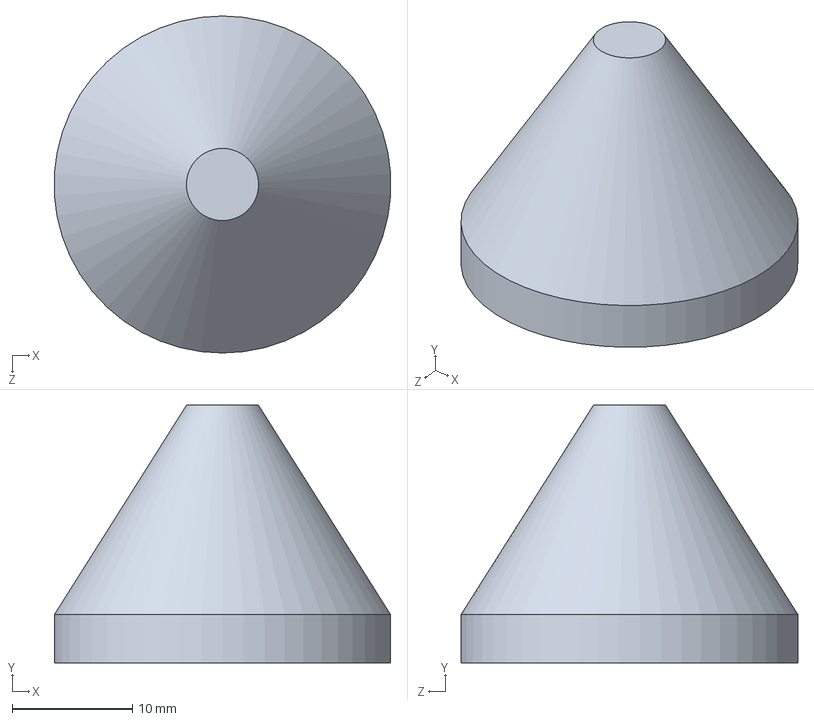
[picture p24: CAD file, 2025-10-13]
Hardware/3D Files/SolidWorks/PiezoCone.SLDPRT
27.9 x 21.4 x 28.0 mm

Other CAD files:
Hardware/3D Files/SolidWorks/Tests/DrumpadTestAssemble.SLDASM
Hardware/3D Files/step & 3mf/Fasteners/DrumpadFastener Ride 77.STEP
Hardware/3D Files/step & 3mf/Fasteners/DrumpadFastener Kick 86.STEP
Hardware/3D Files/step & 3mf/Fasteners/DrumpadFastener LowTom 68.STEP
Hardware/3D Files/SolidWorks/Drumkit Cover.SLDPRT
Hardware/3D Files/SolidWorks/DrumpadStand_Ride.SLDPRT
Hardware/3D Files/SolidWorks/Tests/DrumpadTest_1.SLDPRT
Hardware/3D Files/SolidWorks/Tests/DrumpadTest_2.SLDPRT
Hardware/3D Files/SolidWorks/Tests/DrumpadTest_Fastener_1.SLDPRT
Hardware/3D Files/SolidWorks/Tests/DrumpadTest_Fastener_2.SLDPRT
Hardware/3D Files/step & 3mf/Drumkit Cover.3mf
Hardware/3D Files/step & 3mf/Fasteners/DrumpadFastener Crash 74.STEP
Hardware/3D Files/step & 3mf/Fasteners/DrumpadFastener Hi_Mid_Tom 56.STEP
Hardware/3D Files/step & 3mf/Fasteners/DrumpadFastener Hihat 52.STEP
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

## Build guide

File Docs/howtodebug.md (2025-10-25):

# STM32 Desktop Drumkit - Debugging and Calibration Guide

> Before flashing the final version, please fine-tune the code according to your actual drum pads. Two debugging steps and one parameter calibration are required:

## Code Debugging Before Final Flashing

### 1. Check Drum Pad Waveform and Determine Baseline Values

- Comment out the entire for loop (or all other content in the loop) in the while loop in `cpp_main.cpp`, and uncomment the code block on lines 200-215. Ignore the "unused variables" warning.
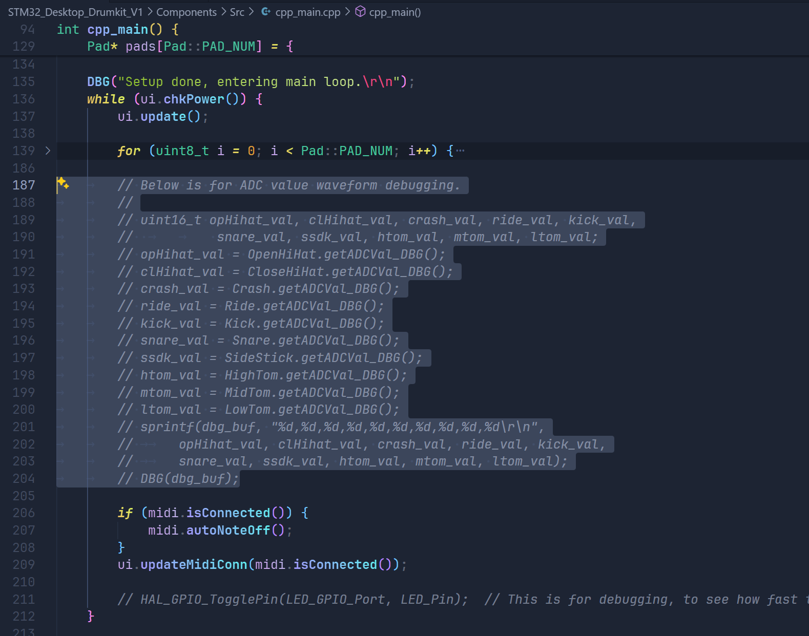
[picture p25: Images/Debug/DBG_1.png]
DBG_1
    
- Flash the firmware. The pin sequence for flashing from left to right is: `SWCLK`, `SWDIO`, `GND`, `3V3`.
- Open a serial plotter (such as SerialPlot), set baud rate to 115200, select the correct COM port, and choose comma as data separator.
- Connect the drum pad's Debug interface, long press the button to power on, then open the computer's serial port. If everything is normal, you should see a waveform like this. When hitting a sensor, you can see changes in the range of 0-4095:
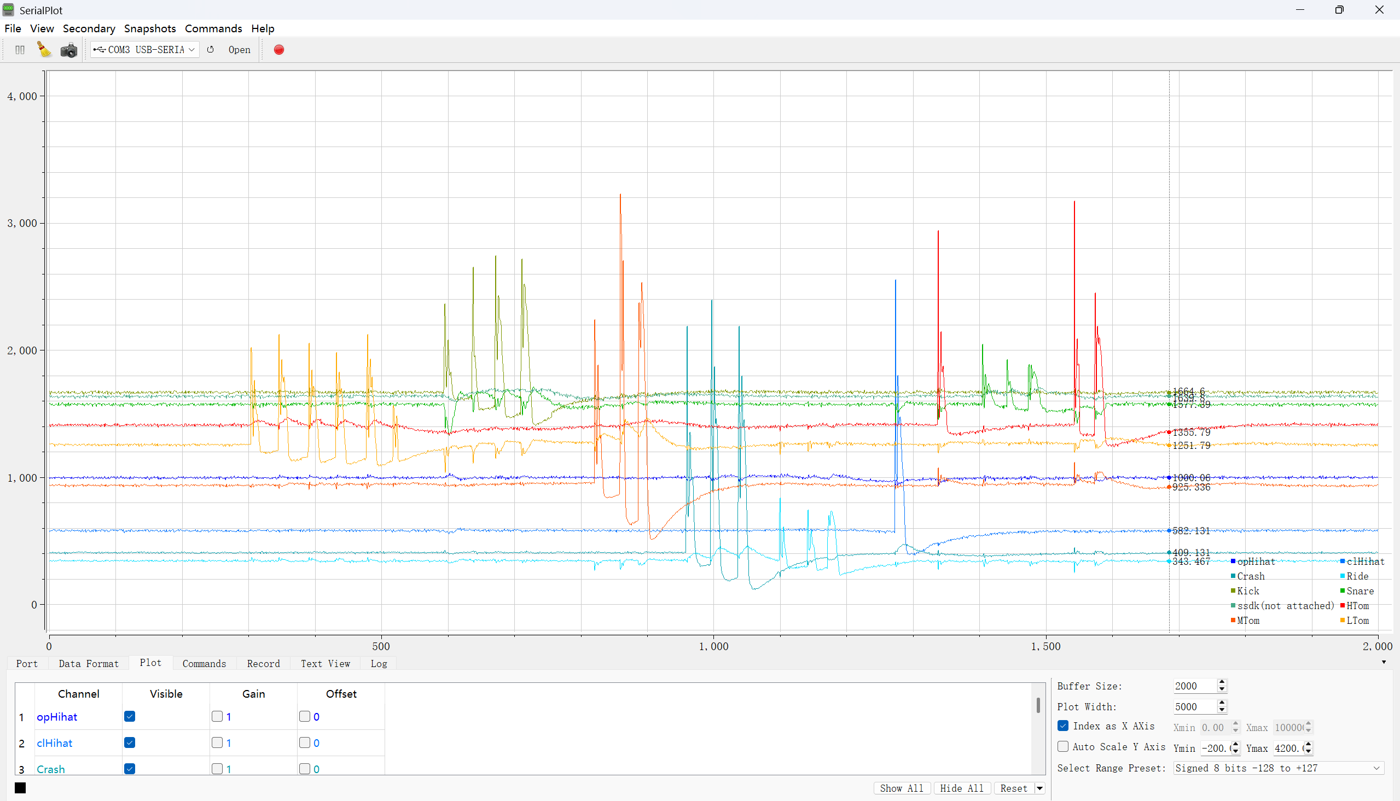
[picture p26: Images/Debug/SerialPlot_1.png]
SerialPlot_1
    
- You will notice slight crosstalk between every two drum pads, which is completely normal and caused by the ADC sampling capacitor charge retention of STM32F4.
- **Most importantly, record the resting ADC value of each sensor. These values determine the `hit_threshold` member variable of the Pad instance. Even if you don't have a serial plotter, please open a serial terminal to record these ten numbers!!**

### 2. Check Drum Pad ADC Peaks

- Restore the code to its initial state, then uncomment the code block on lines 182-190 in `cpp_main.cpp`.
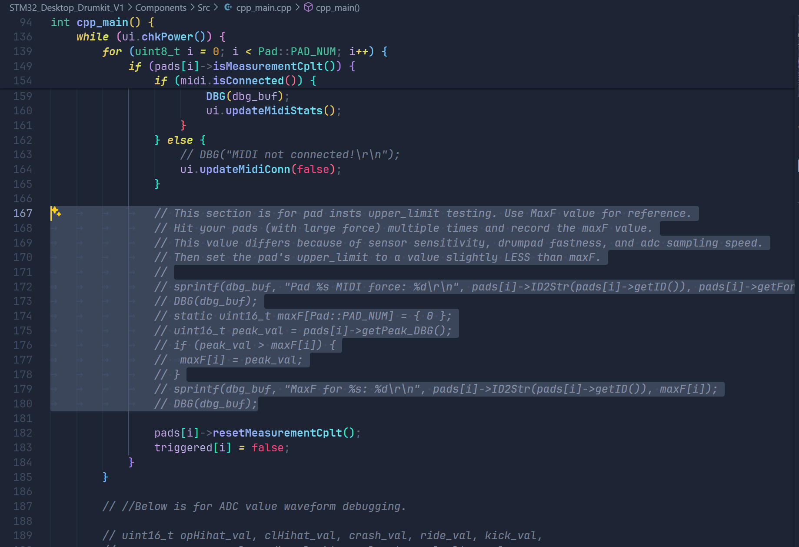
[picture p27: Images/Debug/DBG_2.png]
DBG_2
    
- Flash the firmware
- Open a serial terminal, set baud rate to 115200, select the correct COM port.
- Connect the drum pad's Debug interface, long press the button to power on, open the computer's serial port, try hitting a sensor, you should see output like this:
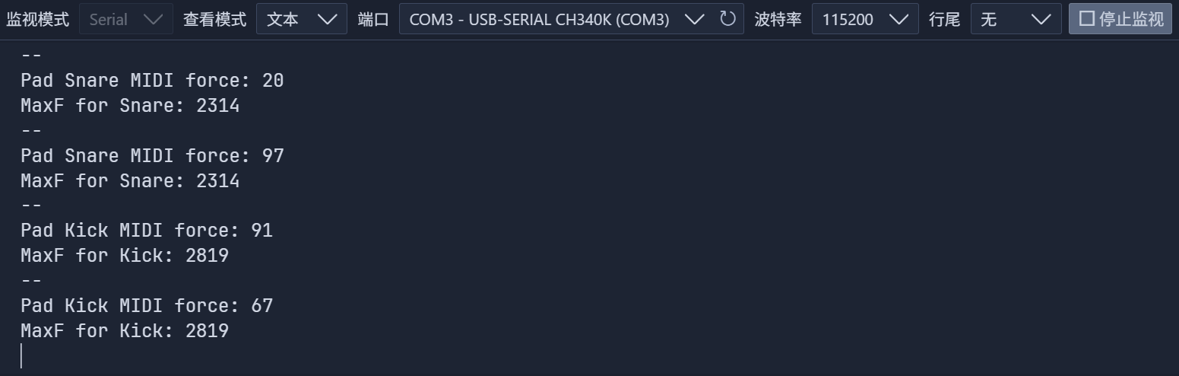
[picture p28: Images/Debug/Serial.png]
Serial
    
- **Hit each sensor dozens of times with different strengths, you will see the MaxF value records the maximum peak value that appeared in all hits**.
- Record the `MaxF` value for each drum pad. These values determine the `upper_limit` member variable of the Pad instance.

## Parameter Calibration Before Final Flashing

You have obtained the `hit_threshold` and `upper_limit` parameters, now you can start fine-tuning the code. I've added a new `config.h` configuration file, so you don't need to search through the code anymore:
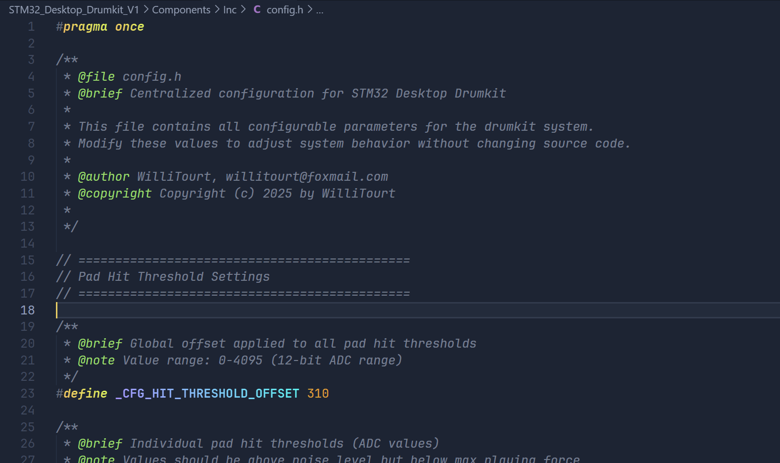
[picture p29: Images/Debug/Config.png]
Config.h
    
- Replace the numbers in `Pad Hit Threshold Settings` section with the resting ADC values you obtained for each sensor.
- Replace the numbers in `Pad Upper Limit Settings` section with the `MaxF` values you obtained for each drum pad. **Set this value slightly lower than MaxF to get better velocity mapping**.
- If you want, you can adjust other parameters such as `_CFG_HIT_THRESHOLD_OFFSET` and `Force Mapping Curve Settings` to get better triggering and velocity mapping. The adjustment technique of `_CFG_HIT_THRESHOLD_OFFSET` is: Using the serial port plotters, in step 1, tap each sensor to observe the amplitude of their waveform transitions. Then, **focus on observing the crosstalk phenomenon and adjust the `_CFG_HIT_THRESHOLD_OFFSET` to a position where the sensor you tap can be easily triggered and is higher than the maximum peak of the sensor with crosstalk**. If you find that the jump amplitude of some sensors is particularly small or particularly large, you can also change the multiplier in front of it separately in `cpp main.cpp`, or directly modify their offset values.

## Other Parameter Adjustments (Optional)

- You can try modifying `_CFG_NOTEOFF_DELAY_MS`, this value is used to delay the NoteOff event. Prevents abrupt sound changes caused by too fast NoteOn and NoteOff events.

- You can try modifying `_CFG_ADC_MEASURING_WINDOW_MS`, this value is the length of the ADC sampling window in milliseconds. Too short a window may cause ADC to fail to get accurate peaks, too long a window will cause response delay.

## Others

~~I plan to optimize the code structure in future updates, create a separate config file to separate parameters from code, making it easier for users to modify.~~

*The config.h has been added, now you can directly configure all parameters in this file :)*

Also, if you feel that the force feedback of a certain drum pad is not good during subsequent use, you can come back and recalibrate the parameters again.

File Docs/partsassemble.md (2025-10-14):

# STM32 Desktop Drumkit - Assembly Guide

> If you've completed the PCB and 3D printing work, congratulations! Now you can proceed to the fun and exciting assembly process ;)

## BOM

This is the component list needed in addition to the PCBs.

| Name | Quantity |
| --- | --- |
| Piezo sensor 27mm (diameter) | 9 |
| Drum trigger foam column 28 * 20mm (diameter * height) | 9 |
| Round foam double-sided tape 25 * 1mm (diameter * thickness) | >=9 |
| GH1.25 cable 6pin (dual-ended, same direction) | 1 |
| GH1.25 cable 2pin (single-ended) | 10 |
| Various other cables | - |
| PET mesh fabric 120 mesh | Half meter width is enough |
| M2 screws (length should not exceed 6mm) | 6 |
| M3 screws (length should not exceed 6mm) | 4 |
| Glue that may be needed | - |
| Tools like tweezers | - |

## Assembly Steps

> Below are the assembly steps. Please follow the order and illustrations. Steps will be presented in the form of "Section Title - A paragraph with one picture".

### Piezo Sensor Fabrication & Installation

1. First prepare the piezo sensors and drum trigger foam columns:
   - Check if the white ceramic part of the piezo sensor is intact, verify the waveform with an oscilloscope.
   - Cut a small groove at the bottom of the foam column to align with the solder points on the piezo sensor, ensuring full contact between the piezo and foam base.

2. Attach the piezo sensor to the foam column, aligning the solder points with the groove.
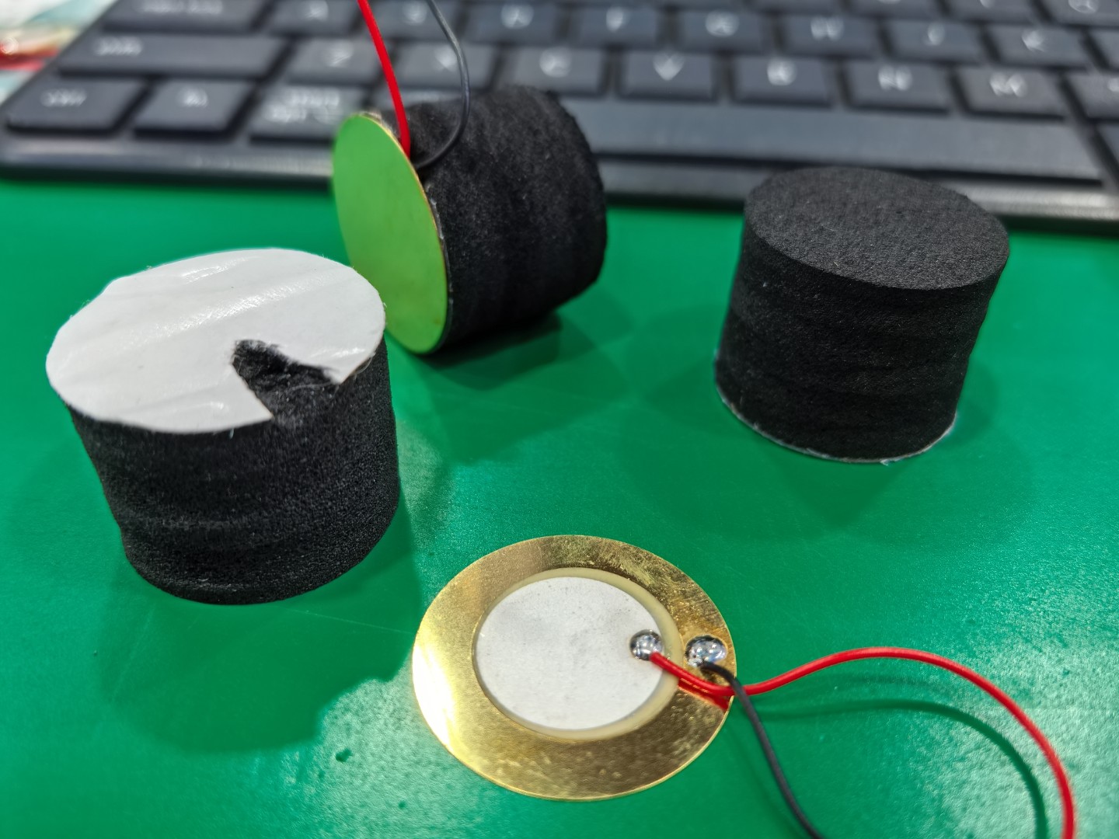
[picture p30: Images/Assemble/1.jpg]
Piezo and foam preparation
   

3. Cut the foam column into a cone shape with scissors, with top diameter about 4mm.
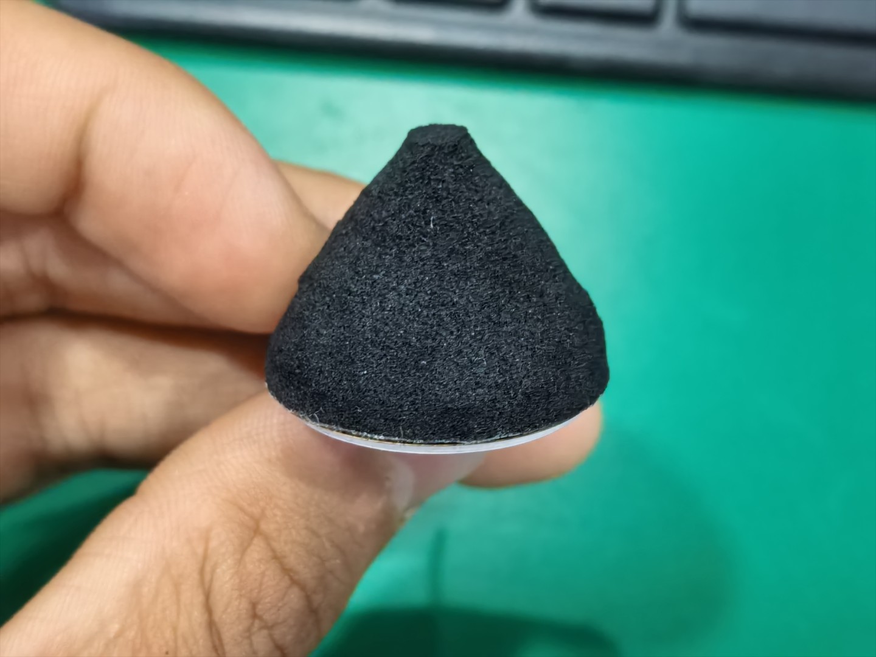
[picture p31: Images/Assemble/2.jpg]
Foam cutting
   

4. Solder the piezo wires to the GH1.25 2P cable. **Pay special attention to the GND and signal positive positions. The red wire may not necessarily be positive - verify the GH connector orientation and PCB signal/GND positions first.** On the PCB, signal is on the left, GND on the right. Ensure proper insulation.
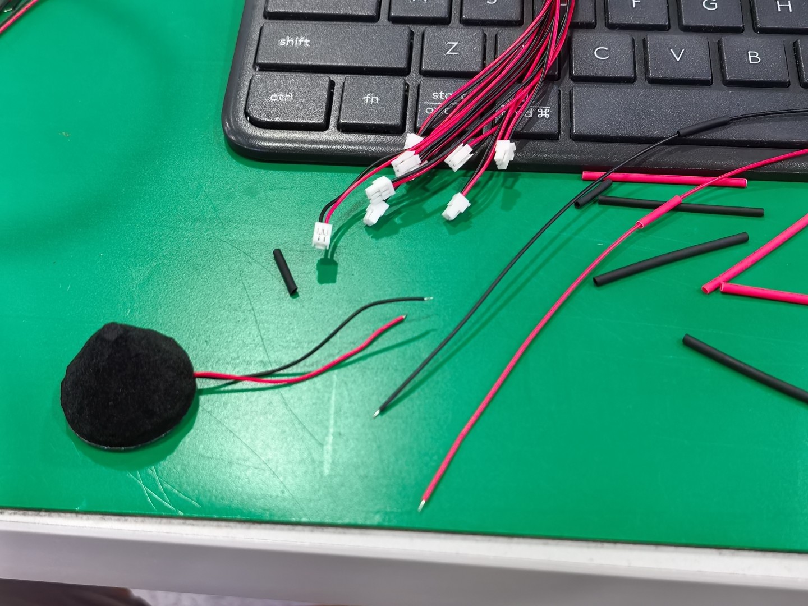
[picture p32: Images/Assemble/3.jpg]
Piezo soldering
   

5. After soldering, connect the sensors to the main board. Connect the UI board and main board using the 6pin GH1.25 cable.
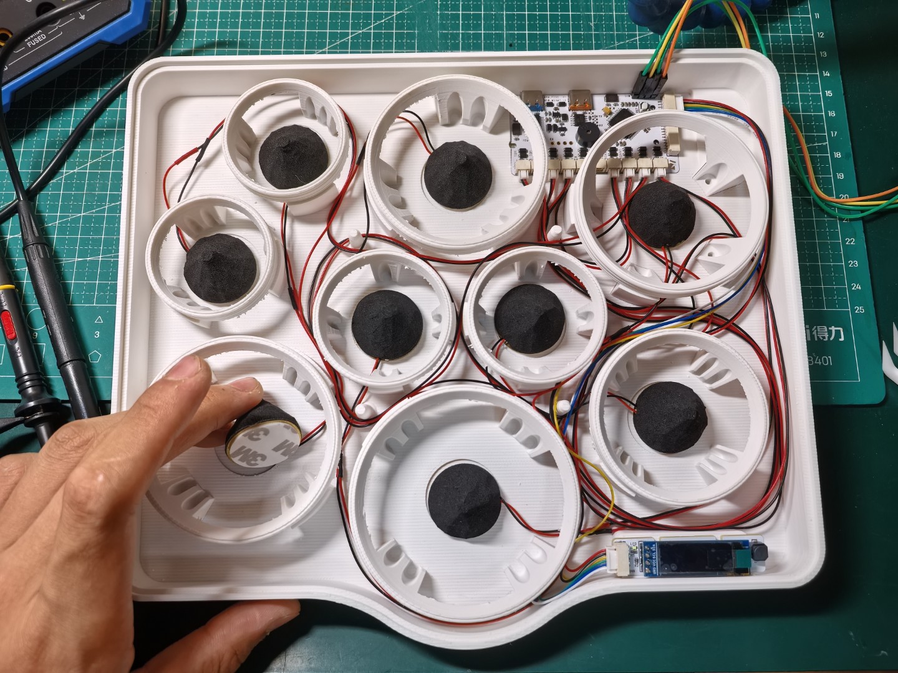
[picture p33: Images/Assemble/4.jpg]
UI and main board connection
   

### Drum Surface Preparation

1. Prepare the drum surfaces. Cut the PET mesh into circles slightly larger than the fastening rings.
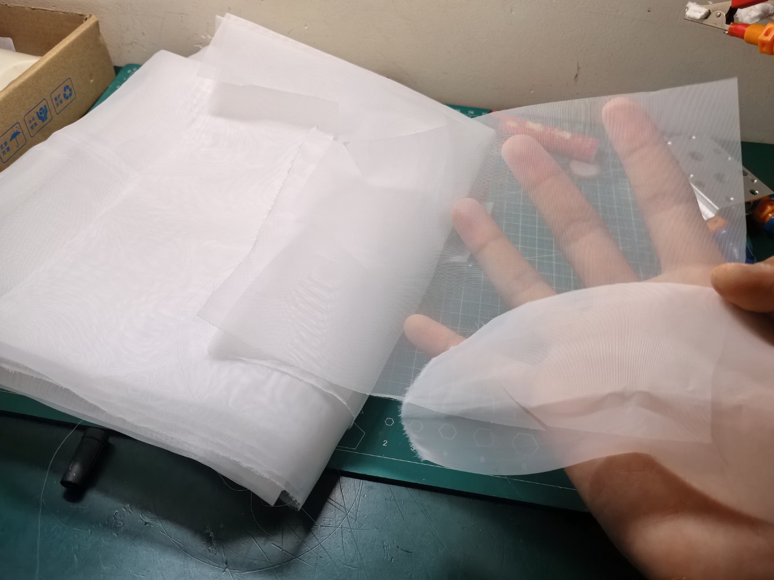
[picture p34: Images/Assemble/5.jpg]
PET mesh
   
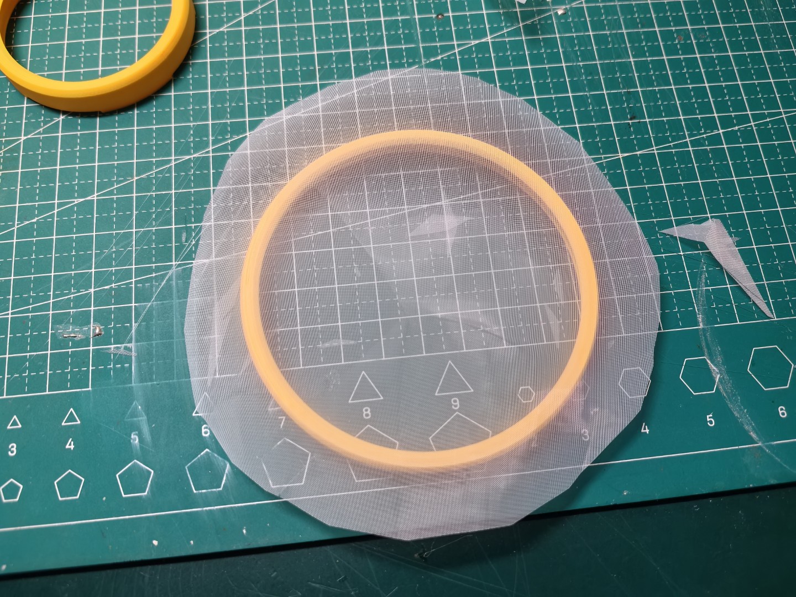
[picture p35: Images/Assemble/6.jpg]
PET mesh cutting
   

2. Each fastening ring can be paired with two mesh pieces for replacement or layered installation.
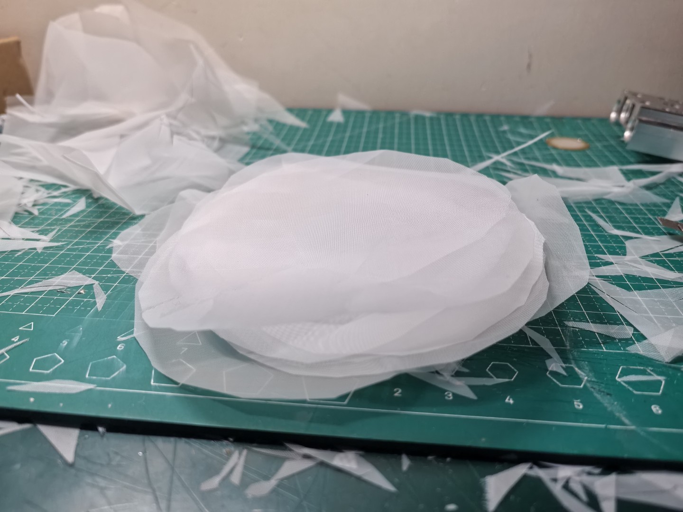
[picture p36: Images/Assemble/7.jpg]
Cut mesh pieces
   

3. Boil these mesh pieces (5-10 minutes) for pre-shrinking treatment, which helps prevent long-term surface sagging.
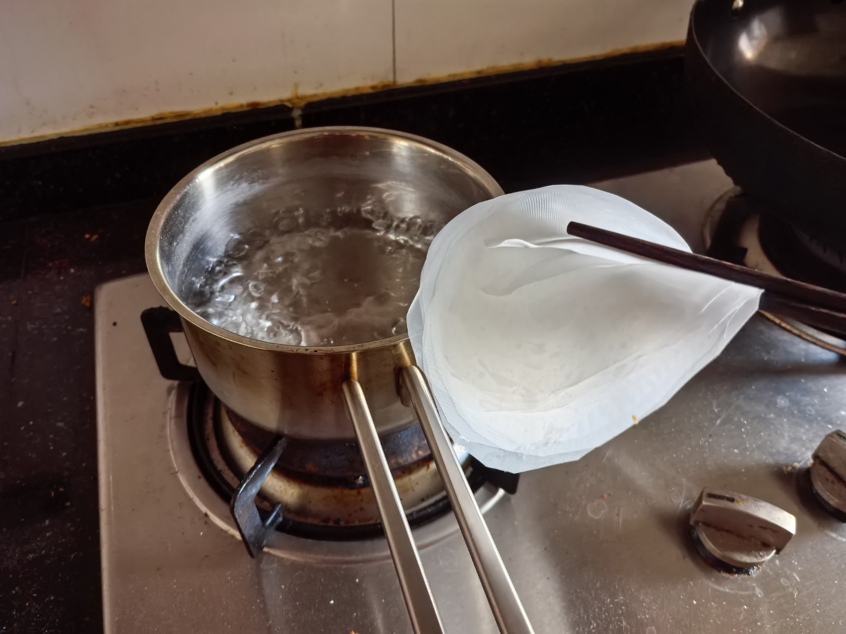
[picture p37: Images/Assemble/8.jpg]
Boiling mesh
   

### Drum Surface Installation and Removal

1. Place the cut mesh pieces in position, aligning with the fastening rings.
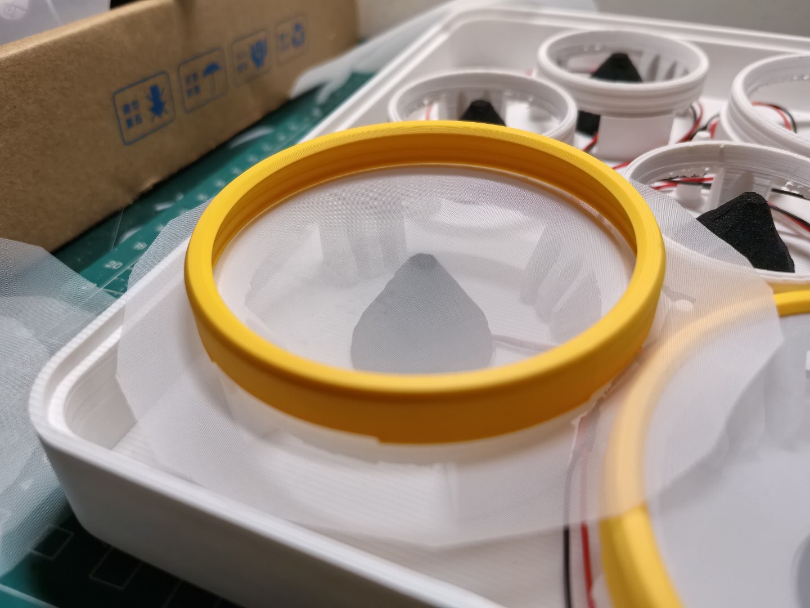
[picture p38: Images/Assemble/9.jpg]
Mesh placement
   

2. Press the fastening rings firmly until there's almost no gap between the ring and main body. This is an interference fit.
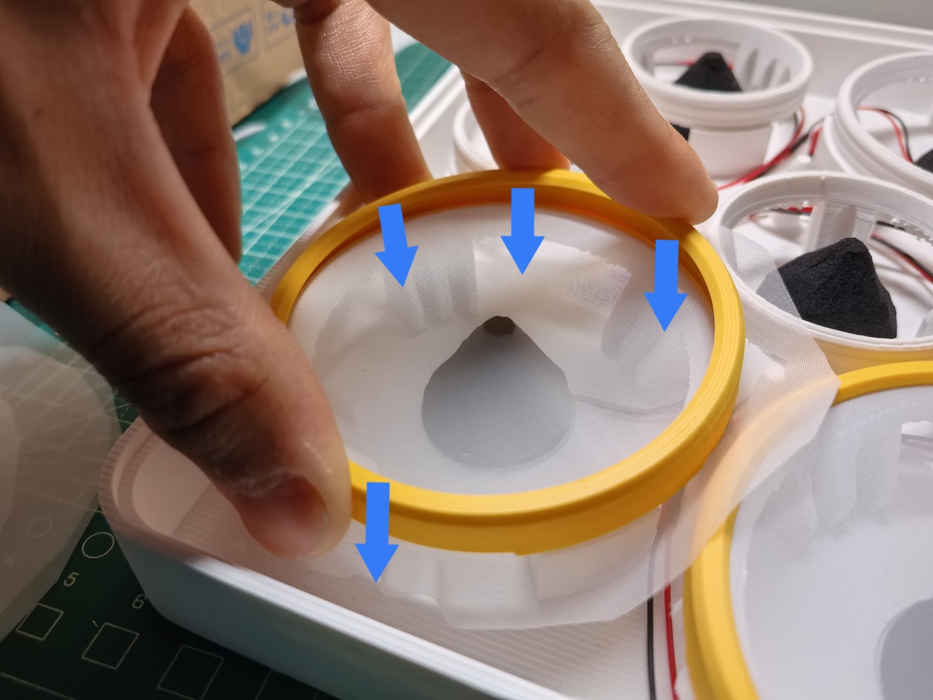
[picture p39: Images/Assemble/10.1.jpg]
   
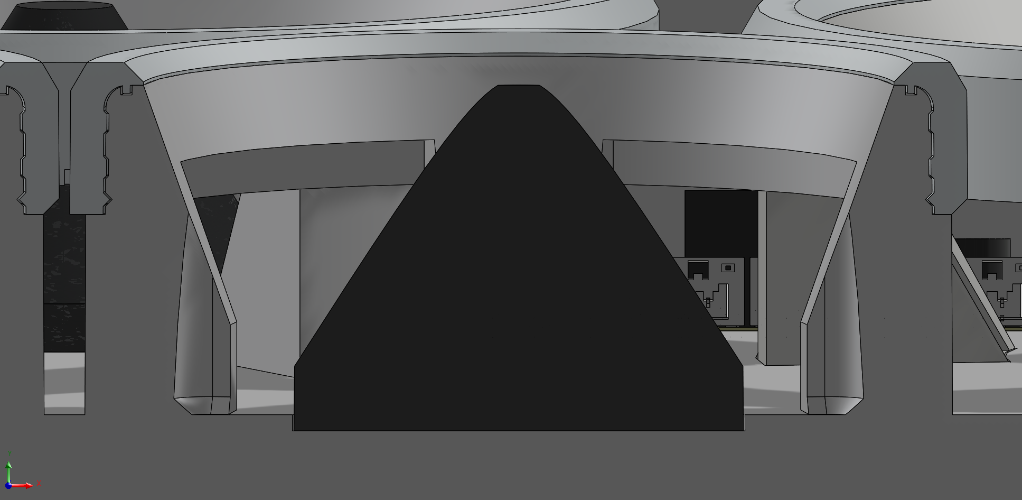
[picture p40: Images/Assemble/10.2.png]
   
   *If the ring is too tight, slightly sand the ring before installation:*
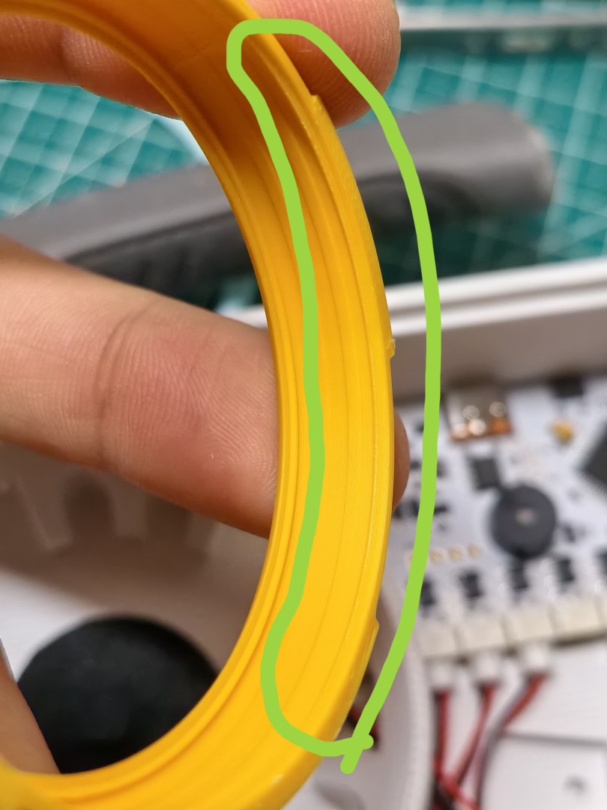
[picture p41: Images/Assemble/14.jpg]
Ring sanding
   

3. Done!
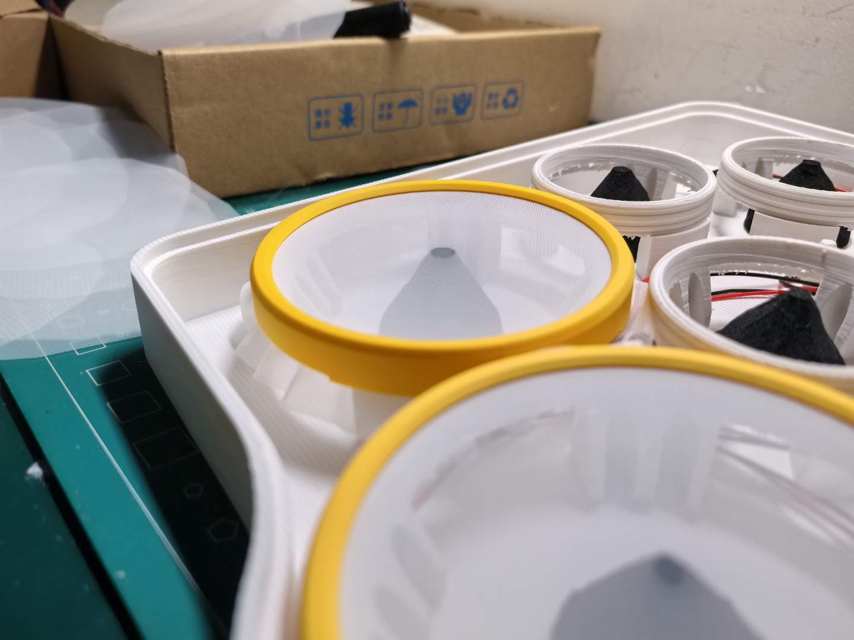
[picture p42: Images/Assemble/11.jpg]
Completed
   

4. To remove the drum surface, simply press the mesh slightly to lift the fastening ring, then pull it out.
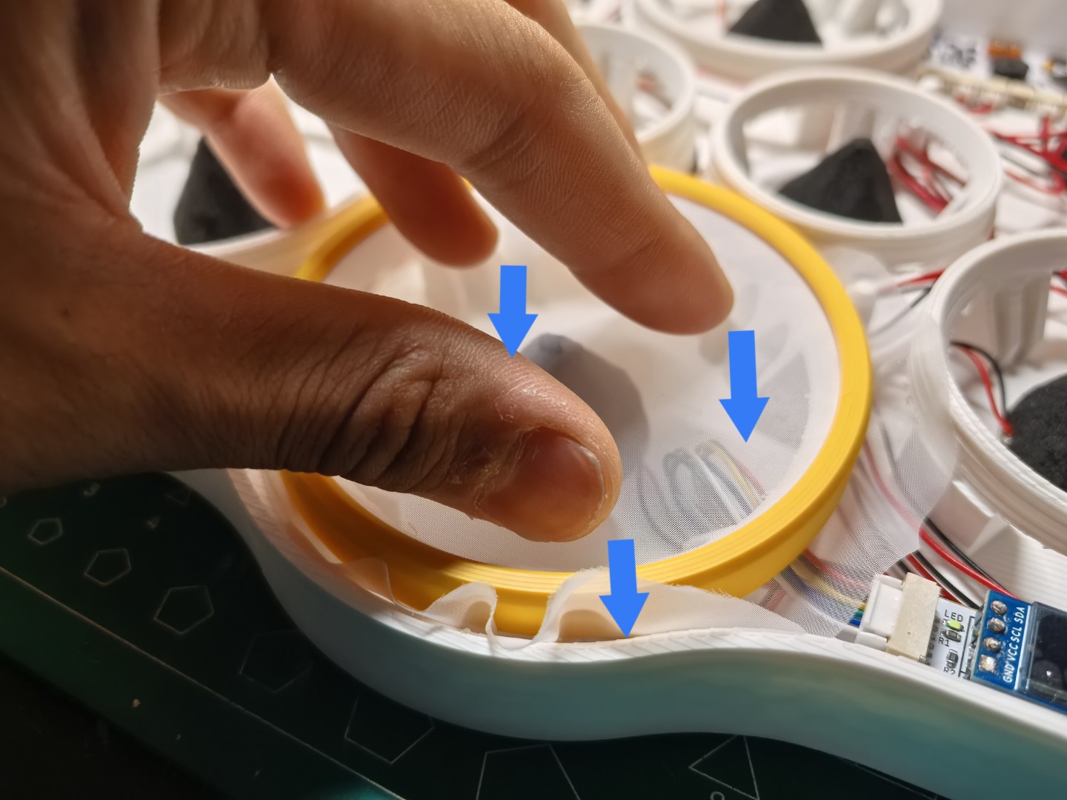
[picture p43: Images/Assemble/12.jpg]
Removal
   

5. If the ring isn't tight enough or the mesh still feels loose, you can install mesh pieces in layers. For layered installation: best to arrange two mesh pieces at a 45 degree angle (at 0 or 90 degrees you'll see moiré patterns, while 45 degrees avoids this).
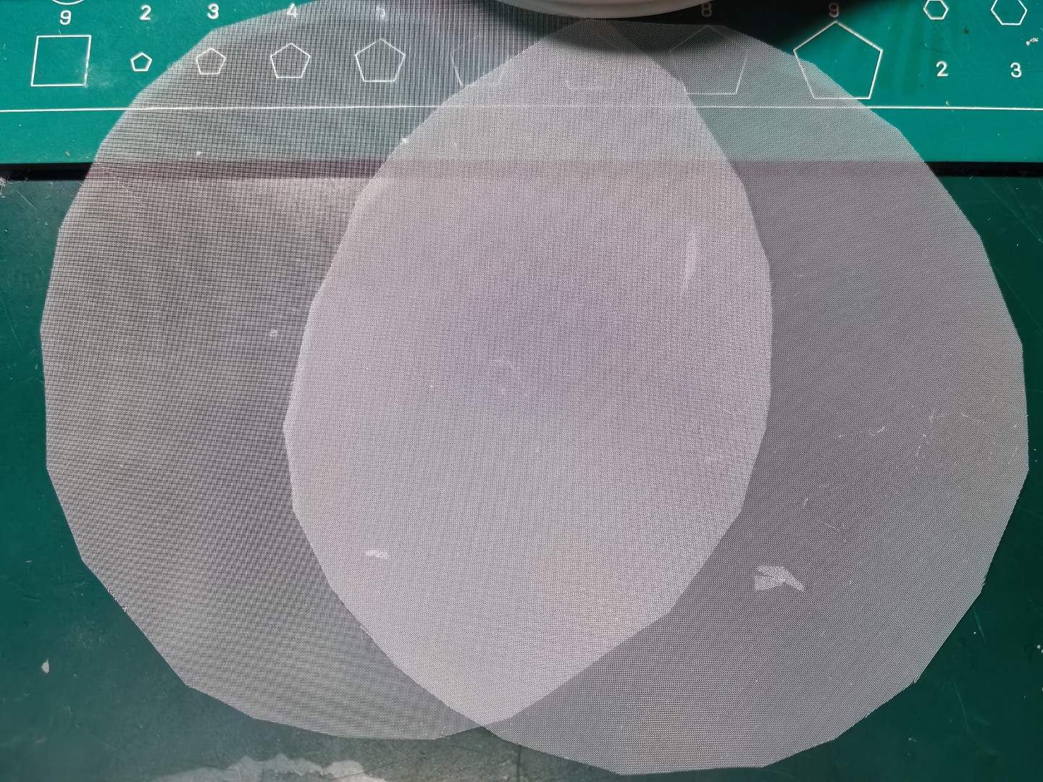
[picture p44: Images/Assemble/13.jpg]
Layered installation
   

### Final Assembly

1. This is the result after installing all drum surfaces. The Ride has a separate stand - its surface shouldn't be installed yet (unlike in this photo), as the stand needs to be fixed first:
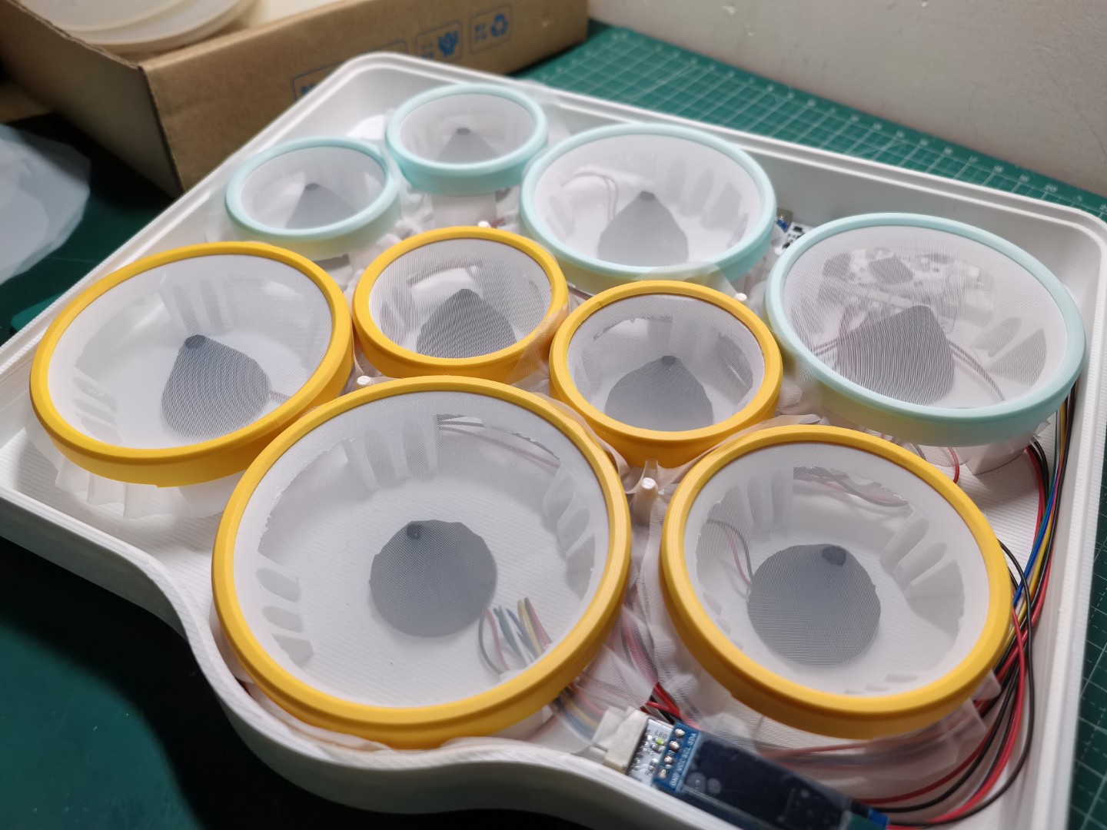
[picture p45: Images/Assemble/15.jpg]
Final look
   

2. Secure the Ride stand and circuit boards, fastening the appropriate screws as shown.
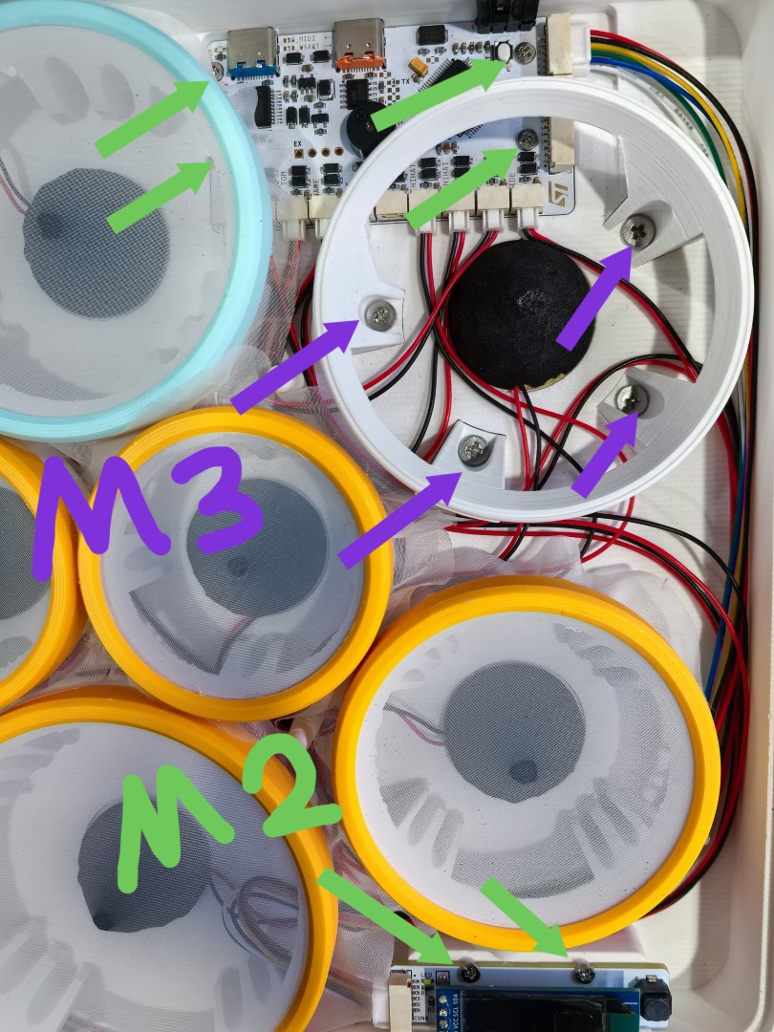
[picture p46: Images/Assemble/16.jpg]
Screw types
   
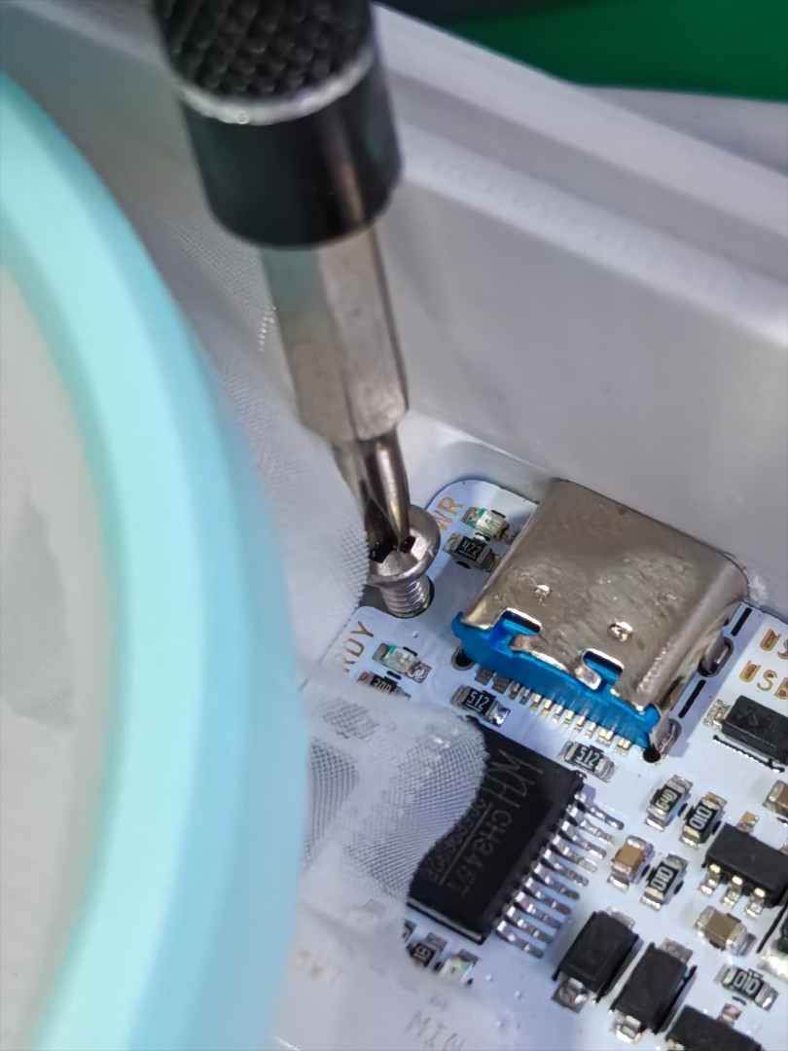
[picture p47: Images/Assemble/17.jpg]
Screw installation
   

3. Install the top cover. Check if the OLED screen fits tightly with the cover.

### **Completed!**

## Additional Tips

- You'll notice three slots at the bottom of the main body - these are for installing angled stands. Sometimes you might prefer using sticks instead of fingers to play, in which case a more angled position would be more comfortable. (Angled stands not provided yet, coming soon)

- The two ports at the back: left is MIDI, right outer one is serial debug port.

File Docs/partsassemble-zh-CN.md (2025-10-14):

# STM32 Desktop Drumkit - 组装指南

> 如果你已经完成了PCB和3D打印的相关工作，那么恭喜你，可以进入好玩又赤鸡的组装环节力 ;)

## BOM

此清单是除了PCB外，还需要准备的组件清单。

| 名称 | 数量 |
| --- | --- |
| 压电陶瓷片 27mm (直径) | 9 |
| 电子鼓触发海绵柱28 * 20mm (直径 * 高) | 9 |
| 圆形泡沫双面胶 25 * 1mm (直径 * 厚) | >=9 |
| GH1.25 排线 6pin (双头**同向**) | 1 |
| GH1.25 排线 2pin (单头) | 10 |
| 若干其他线束 | - |
| PET 网布 120目左右 | 半米宽完全够 |
| M2 螺丝 (长度不应超过6mm) | 6 |
| M3 螺丝 (长度不应超过6mm) | 4 |
| 可能用到的胶水 | - |
| 镊子等工具 | - |

## 组装步骤

> 以下是组装步骤，请按照顺序和图示依次进行。步骤将会以“阶段小标题 - 一段文字一幅图”的形式呈现。

### 压电传感器制作 & 安装

1. 首先对压电片和电子鼓触发海绵柱进行预处理：
    - 压电片一定要检查白色陶瓷部分是否完整，示波器验证波形是否正常。
    - 海绵柱需要用工具在底部切出一个小槽，用于对齐压电片上的焊锡点，使压电片完全接触海绵底面。

2. 将压电片和海绵柱粘贴到一起，注意对齐焊点和小槽。
    压电片和海绵柱预处理

3. 将海绵柱用剪刀剪成锥状，顶面直径约4mm。
    海绵柱剪切

4. 将压电片线端焊接到GH1.25 2P线束上，**一定要注意GND和正极信号的位置，你以为的红色不一定就是正极，一定要先确认GH接头的方向和PCB上信号/GND的位置**，PCB上信号在左，GND在右。注意隔离。
    压电片线端焊接

5. 焊接完成后，即可将传感器接入主板。将UI板和主板通过6pin GH1.25 排线连接。
    UI板和主板连接

### 鼓面处理

1. 接下来处理鼓面。将PET网布裁成比紧固环大两圈的圆形。
    PET网布
    PET网布裁剪

2. 每个紧固环可以配两张网布，便于替换或是叠加安装。
    裁好的网布

3. 将这些剪好的网布拿去煮一下（5到10分钟），这是预收缩处理，可以改善长时间的网面塌陷问题。
    煮网布

### 鼓面安装和拆卸

1. 将剪好的网布放在对应位置，上方先对好紧固环的位置。
    网布安装位置

2. 使劲按压紧固环！直到紧固环和主体部分几乎无缝隙。这是一种过盈配合。
    紧固环安装
    紧固环安装
    *如果你发现紧固环太紧，请先略微打磨此环的位置，再进行安装：*
    紧固环打磨

3. 完成！
    完成

4. 若要拆卸鼓面，直接稍稍用力按压网面即可，此时紧固环会直接翘起，再拔出即可。
    拆卸

5. 如果你发现紧固环不那么紧，或者网面仍然有点松弛，可以叠加安装网布。叠加安装需注意：两张网布之间最好呈45度角（0度或90度时，你可以看到网面叠加后看起来有摩尔纹一样的图案，45度则没有。）
    叠加安装

### 最终组装

1. 这是完成所有鼓面安装后的效果。Ride是独立支架，鼓面应先不安装，不应该像图中一样已安装好，因为稍后需先固定支架：
    效果

2. 固定Ride支架以及电路板，按照图示固定相应的螺丝。
    螺丝类型
    螺丝安装

3. 盖上顶板。此时检查OLED屏幕和顶板是否贴紧。

### **完成！**

## 其他提示

- 你可以看到，主体底部有三个槽口，这是用以加装斜面支架的。有些时候你可能会希望使用棒子而不是手指来敲击，这时候用一个更斜的角度会更舒服。（斜面支架暂时未提供，稍后）

- 背部的两个接口，左侧为MIDI接口，右侧靠外的为串口调试口。

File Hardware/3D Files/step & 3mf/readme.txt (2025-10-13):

.3mf files are Bambu Studio project files, you can directly use them if you are also Bambu Studio User
.3mf 文件是Bambu Studio生成的项目文件，如果你使用Bambu Studio则请直接使用3mf文件进行打印

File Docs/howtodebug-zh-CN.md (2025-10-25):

# STM32 Desktop Drumkit - 调试与参数标定指南

> 正式版本烧录前，请根据你鼓垫的实际情况微调代码。具体需要如下两次调试以及一次参数微调：

## 正式烧录前的代码调试

### 1. 检查鼓垫波形，确定基准值

- 注释掉`cpp_main.cpp`中while循环的整个for循环（或所有循环中的其他内容），取消注释200-215行的代码块。不需要管"unused variables"的警告。
    DBG_1
- 烧录固件，烧录引脚顺序从左到右为：`SWCLK`、`SWDIO`、`GND`、`3V3`。
- 打开串口绘图仪(如SerialPlot等)，设置波特率为115200，选择正确的串口号，数据分割选择逗号。
- 接好鼓垫的Debug接口，长按按键开机，然后打开电脑串口。如果一切正常，你应该可以看到类似这样的波形，敲击某个传感器，可以看到0-4095范围内的变化：
    SerialPlot_1
- 你会发现存在轻微的鼓垫两两串扰现象，这是完全正常的，由STM32F4的ADC采样电容电荷滞留导致。
- **重要的是，请记录下每个传感器的静止基准ADC值，这些值决定Pad实例的`hit_threshold`成员变量。即使你没有串口绘图仪，也请打开串口助手记录这十个数字！！**

### 2. 检查鼓垫ADC峰值

- 还原代码到初始状态，然后取消注释`cpp_main.cpp`中182-190行的代码块。
    DBG_2
- 烧录固件
- 打开串口助手，设置波特率为115200，选择正确的串口号。
- 接好鼓垫的Debug接口，长按按键开机，打开电脑串口，试着敲击某个传感器，你应该可以看到类似这样的输出：
    Serial
- **请用不同力度，重复敲击每个传感器数十次，你会看到MaxF值记录下了所有敲击里出现过的最大峰值**。
- 记录下每个鼓垫的`MaxF`，这些值决定Pad实例的`upper_limit`成员变量。

## 正式烧录前的参数微调

你刚才得到了`hit_threshold`和`upper_limit`两个参数，现在可以开始微调代码了。我已添加新的`config.h`配置文件，不再需要到处翻代码了:
    Config.h
- 将`Pad Hit Threshold Settings`部分每个独立Pad的数字替换为你得到的每个传感器的静止基准ADC值。
- 将`Pad Upper Limit Settings`部分每个Pad的数字替换为你得到的每个鼓垫的`MaxF`值。**将此值设置成稍微低于MaxF的值，以得到更好的力度映射**。
- 如果你想的话，可以调整其他诸如`_CFG_HIT_THRESHOLD_OFFSET`和`Force Mapping Curve Settings`部分的值，以得到更好的触发效果和力度映射。`_CFG_HIT_THRESHOLD_OFFSET`的调整技巧是：使用串口绘图仪，在第1步骤时，敲击各个传感器，观察它们的波形跳变幅度，然后**重点观察串扰现象，将`_CFG_HIT_THRESHOLD_OFFSET`调整到你敲击的传感器能轻松触发，且高于含串扰的传感器的最大峰值的位置**。如果你发现有些传感器跳变幅度特别小或是特别大，也可以单独在`cpp_main.cpp`中更改其前面的乘数，或者直接修改它们的偏移值。
- 烧录固件，测试效果 ;)

## 其他值的微调 （可选）

- 可以尝试修改`_CFG_NOTEOFF_DELAY_MS`，这个值用于延迟NoteOff事件。防止过快的NoteOn事件和NoteOff事件导致的音色跳跃。

- 可以尝试修改`_CFG_ADC_MEASURING_WINDOW_MS`，此值是ADC采样窗口的长度，单位为毫秒。过短的窗口会导致ADC可能得不到精确的峰值，过长的窗口会导致响应延迟。

## 其他

~~我准备在之后的更新中优化代码结构，单独建立一个config文件，将参数和代码分离，方便用户修改。~~

*已完成config.h添加，现在你可以直接在此文件中配置所有参数 :)*

还有，如果你在之后使用过程中感觉某个鼓垫的力度反馈不太好时，也可以回来重新标定一遍参数。

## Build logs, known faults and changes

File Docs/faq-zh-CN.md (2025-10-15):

# STM32 Desktop Drumkit - 常见问题 FAQ

## 鼓垫敲击后，电脑发不出声音？

1. 检查屏幕上是否提示 "MIDI: READY!", 如果没有, 请检查是否正确连接了MIDI接口。
2. 检查对应压电片的正负极是否正确连接。参考[组装指南](../Docs/partsassemble-zh-CN.md)中的`压电传感器制作 & 安装`部分的第四点。
3. 检查DAW中的MIDI连接设置，以及MIDI映射。
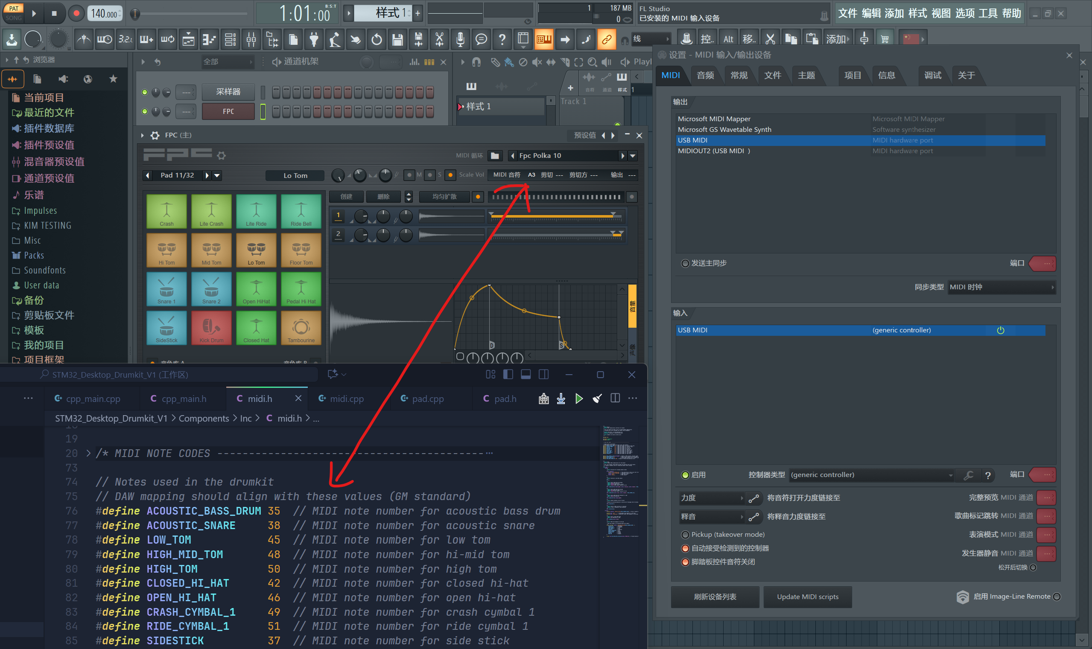
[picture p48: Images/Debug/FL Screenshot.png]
MIDI设置
    
4. 重新调试压电片，确保它的波形是正常的。

## 力度输出不准？

1. 重新微调参数，详情请见[调试与参数标定指南](../Docs/howtodebug-zh-CN.md)。
2. 这还有一部分采样率的影响，如果压电片峰值波形十分短，STM32可能无法捕捉到最准确的峰值。

## 有串扰/有误触发？

1. 检查你的`hit_threshold`和`HIT_THRESHOLD_OFFSET`参数。详情请见[调试与参数标定指南](../Docs/howtodebug-zh-CN.md)。

2. 如果你怎么调参数都还是有串扰，请检查含串扰问题的压电片波形是否在敲击瞬间有很强的跳变，尝试更换压电片。也可尝试对信号处理电路的滤波电容换用更高的电容值。

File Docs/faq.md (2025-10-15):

# STM32 Desktop Drumkit - Frequently Asked Questions (FAQ)

## No sound from computer after hitting the drum pad?

1. Check if the screen displays "MIDI: READY!". If not, check if the MIDI interface is properly connected.
2. Verify the polarity of the piezo sensor connections. Refer to the `Piezo Sensor Fabrication & Installation` section in the [Assembly Guide](../Docs/partsassemble.md).
3. Check the MIDI connection settings and MIDI mapping in your DAW.
    MIDI Settings
4. Recalibrate the piezo sensor to ensure its waveform is normal.

## Inaccurate velocity output?

1. Fine-tune the parameters. See details in the [Debugging and Calibration Guide](../Docs/howtodebug.md).
2. This could also be affected by the sampling rate. If the peak waveform of the piezo sensor is very short, the STM32 might not be able to capture the most accurate peak.

## Experiencing crosstalk/false triggering?

1. Check your `hit_threshold` and `HIT_THRESHOLD_OFFSET` parameters. See details in the [Debugging and Calibration Guide](../Docs/howtodebug.md).

2. If you still experience crosstalk after parameter adjustment, check if the problematic piezo sensor's waveform has strong jumps at the moment of hitting. Try replacing the piezo sensor. You can also try using a higher capacitance value for the filter capacitor in the signal processing circuit.

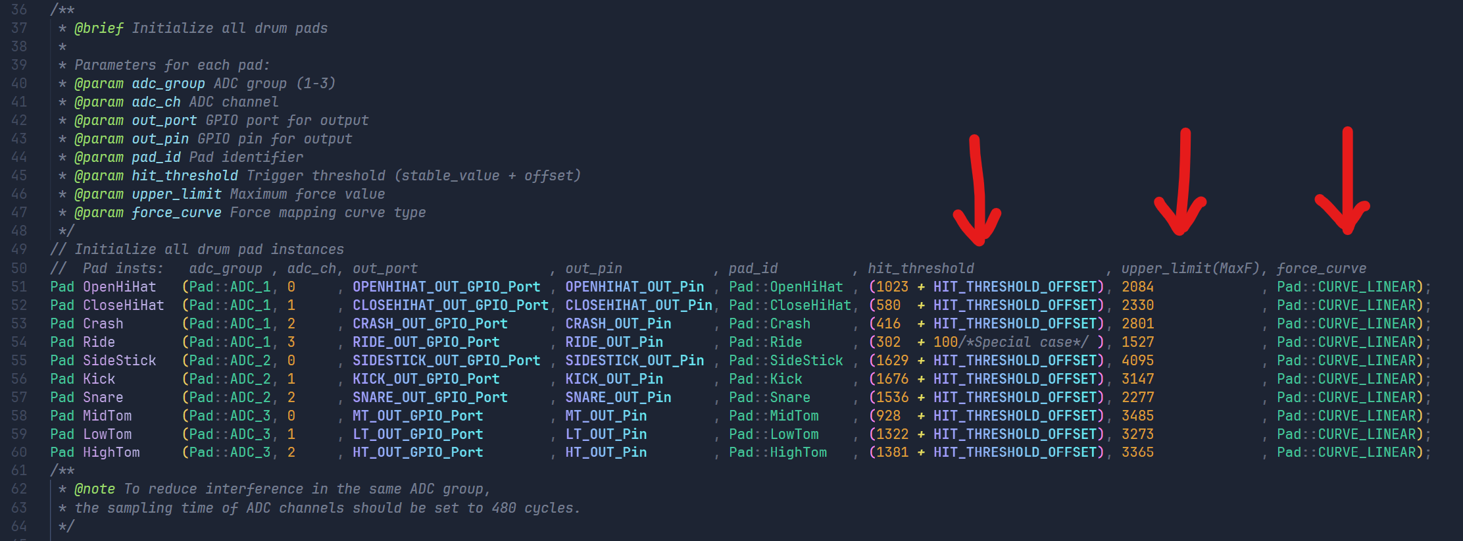
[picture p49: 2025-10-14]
Images/Debug/Code Adjustment.png

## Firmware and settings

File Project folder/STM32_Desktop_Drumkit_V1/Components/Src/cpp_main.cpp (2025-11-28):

/**
 * @file cpp_main.cpp
 * @version 1.0.3
 * 
 * @brief Main application logic for drumkit
 * 
 * This file implements the main application logic including:
 * - Pad initialization and configuration
 * - MIDI communication setup
 * - Main processing loop
 * - User interface updates
 * 
 * @author WilliTourt, willitourt@foxmail.com
 * @copyright Copyright (c) 2025 by WilliTourt
 * 
 * @note Comments are mostly written by AI
 * 
 * @CHANGELOG:
 * - 2025-09-14: V1 plan complete, file created
 * - 2025-10-13: V1.0.0 release
 * - 2025.10-20: Added a config header file for all configuration constants
 * - 2025.10-21: Added buzzer class support
 * - 2025.10.25: Added _CFG_FORBID_LOW_VELOCITY option to optimize low velocity detection,
 * 				 and a multiplier for the hit threshold offset.
 * 
 */

#include "cpp_main.h"
#include "adc.h"
#include "pad.h"
#include "midi.h"
#include "ui.h"

/**
 * @brief Hit threshold offset value
 * 
 * This offset is used to reduce interference possibility.
 * Higher values for more noisy environments, but may miss light hits.
 * Hit threshold is set as (stable_value + offset)
 */
#define HIT_THRESHOLD_OFFSET _CFG_HIT_THRESHOLD_OFFSET

/**
 * @brief Initialize all drum pads
 * 
 * Parameters for each pad:
 * @param adc_group ADC group (1-3)
 * @param adc_ch ADC channel
 * @param out_port GPIO port for output
 * @param out_pin GPIO pin for output 
 * @param pad_id Pad identifier
 * @param hit_threshold Trigger threshold (stable_value + offset)
 * @param upper_limit Maximum force value
 * @param force_curve Force mapping curve type
 */
// Initialize all drum pad instances
//  Pad insts:   adc_group , adc_ch, out_port          		 , out_pin           , pad_id         , hit_threshold           						          , upper_limit(MaxF), force_curve
Pad OpenHiHat 	(Pad::ADC_1, 0     , OPENHIHAT_OUT_GPIO_Port , OPENHIHAT_OUT_Pin , Pad::OpenHiHat , (_CFG_OPHIHAT_HIT_THRESHOLD + 1.20 * HIT_THRESHOLD_OFFSET), _CFG_OPHIHAT_MAXF, (Pad::ForceMappingCurve)_CFG_OPHIHAT_FORCE_CURVE_TYPE);
Pad CloseHiHat	(Pad::ADC_1, 1     , CLOSEHIHAT_OUT_GPIO_Port, CLOSEHIHAT_OUT_Pin, Pad::CloseHiHat, (_CFG_CLHIHAT_HIT_THRESHOLD + 1.00 * HIT_THRESHOLD_OFFSET), _CFG_CLHIHAT_MAXF, (Pad::ForceMappingCurve)_CFG_CLHIHAT_FORCE_CURVE_TYPE);
Pad Crash	  	(Pad::ADC_1, 2     , CRASH_OUT_GPIO_Port	 , CRASH_OUT_Pin	 , Pad::Crash	  , (_CFG_CRASH_HIT_THRESHOLD   + 0.65 * HIT_THRESHOLD_OFFSET), _CFG_CRASH_H_MAXF, (Pad::ForceMappingCurve)_CFG_CRASH_FORCE_CURVE_TYPE  );
Pad Ride		(Pad::ADC_1, 3     , RIDE_OUT_GPIO_Port		 , RIDE_OUT_Pin		 , Pad::Ride	  , (_CFG_RIDE_HIT_THRESHOLD	+ 0.90 * HIT_THRESHOLD_OFFSET), _CFG_RIDE_MAXF   , (Pad::ForceMappingCurve)_CFG_RIDE_FORCE_CURVE_TYPE   );
Pad SideStick	(Pad::ADC_2, 0     , SIDESTICK_OUT_GPIO_Port , SIDESTICK_OUT_Pin , Pad::SideStick , (_CFG_SSTK_HIT_THRESHOLD    + 1.50 * HIT_THRESHOLD_OFFSET), _CFG_SSTK_MAXF   , (Pad::ForceMappingCurve)_CFG_SSTK_FORCE_CURVE_TYPE   );
Pad Kick		(Pad::ADC_2, 1     , KICK_OUT_GPIO_Port		 , KICK_OUT_Pin		 , Pad::Kick	  , (_CFG_KICK_HIT_THRESHOLD	+ 1.02 * HIT_THRESHOLD_OFFSET), _CFG_KICK_MAXF   , (Pad::ForceMappingCurve)_CFG_KICK_FORCE_CURVE_TYPE   );
Pad Snare		(Pad::ADC_2, 2     , SNARE_OUT_GPIO_Port	 , SNARE_OUT_Pin	 , Pad::Snare	  , (_CFG_SNARE_HIT_THRESHOLD   + 1.10 * HIT_THRESHOLD_OFFSET), _CFG_SNARE_MAXF  , (Pad::ForceMappingCurve)_CFG_SNARE_FORCE_CURVE_TYPE  );
Pad MidTom		(Pad::ADC_3, 0     , MT_OUT_GPIO_Port		 , MT_OUT_Pin		 , Pad::MidTom	  , (_CFG_MIDTOM_HIT_THRESHOLD  + 1.00 * HIT_THRESHOLD_OFFSET), _CFG_MIDTOM_MAXF , (Pad::ForceMappingCurve)_CFG_MIDTOM_FORCE_CURVE_TYPE );
Pad LowTom		(Pad::ADC_3, 1     , LT_OUT_GPIO_Port		 , LT_OUT_Pin		 , Pad::LowTom	  , (_CFG_LOWTOM_HIT_THRESHOLD  + 1.20 * HIT_THRESHOLD_OFFSET), _CFG_LOWTOM_MAXF , (Pad::ForceMappingCurve)_CFG_LOWTOM_FORCE_CURVE_TYPE );
Pad HighTom		(Pad::ADC_3, 2     , HT_OUT_GPIO_Port		 , HT_OUT_Pin		 , Pad::HighTom	  , (_CFG_HIGHTOM_HIT_THRESHOLD + 1.32 * HIT_THRESHOLD_OFFSET), _CFG_HIGHTOM_MAXF, (Pad::ForceMappingCurve)_CFG_HIGHTOM_FORCE_CURVE_TYPE);
/**
 * @note To reduce interference in the same ADC group,
 * the sampling time of ADC channels should be set to 480 cycles.
 */

Midi midi; // MIDI communication handler

bool triggered[Pad::PAD_NUM] = { false }; // Pad trigger state array

char dbg_buf[128]; // Debug message buffer

/**
 * @brief Send debug message via UART
 * @param str Debug message string
 */
void DBG(const char* str) {
	if (ui.isDebugLogEnabled()) {
		HAL_UART_Transmit(&huart1, (uint8_t*)str, strlen(str), 100);
	}
}

/**
 * @brief Main application entry point
 * 
 * Initializes hardware and enters main processing loop:
 * 1. Waits for power on
 * 2. Initializes ADC DMA for pad sensing
 * 3. Initializes UI components
 * 4. Enters main processing loop:
 *    - Updates UI
 *    - Processes pad hits
 *    - Handles MIDI communication
 * 
 * @return int Application exit status (never returns)
 */
int cpp_main() {
	
	ui.buttonInit( _CFG_BUTTON_DEBOUNCE_TIME_MS,
				   _CFG_BUTTON_SINGLECLICK_MAXTIME_MS,
				   _CFG_BUTTON_LONGPRESS_MINTIME_MS,  
				   _CFG_BUTTON_MULTICLICK_MAXTIME_MS );
	
	while (!ui.chkPower()) { ui.buttonTick(); }
	DBG("Power on.\r\n");

	HAL_ADC_Start_DMA(&hadc1, (uint32_t*)Pad::adc1_buf, ADC1_PAD_NUMS);
	HAL_ADC_Start_DMA(&hadc2, (uint32_t*)Pad::adc2_buf, ADC2_PAD_NUMS);
	HAL_ADC_Start_DMA(&hadc3, (uint32_t*)Pad::adc3_buf, ADC3_PAD_NUMS);

	DBG("OLED init...\r\n");
	ui.init();
	ui.welcome();

	// if (!oled.begin()) {
	// 	DBG("OLED Initialization Failed.\r\n");
	// 	while (true);
	// }
	// oled.printText(0, 0, "Debugging", 16);
	// oled.printText(0, 2, "OLED Test", 8);
	// for (uint8_t y = 0; y < 32; y++) {
	// 	for (uint8_t x = 0; x < 128; x++) {
	// 		oled.setPixel(x, y, true);
	// 	}
	// }
	// for (uint8_t y = 2; y < 30; y++) {
	// 	for (uint8_t x = 2; x < 126; x++) {
	// 		oled.setPixel(x, y, false);
	// 	}
	// }

	midi.isConnected() ? DBG("MIDI connected.\r\n") : DBG("MIDI not connected.\r\n");

	Pad* pads[Pad::PAD_NUM] = {
		&OpenHiHat, &CloseHiHat, &Crash, &Ride,
		&SideStick, &Kick, &Snare,
		&MidTom, &LowTom, &HighTom
	};

	DBG("Setup done, entering main loop.\r\n");
	while (ui.chkPower()) {
		ui.update();

		if (ui.getMode() == UI::DisplayMode::PAGE) {
			for (uint8_t i = 0; i < Pad::PAD_NUM; i++) {
				pads[i]->detectHit();
				if (pads[i]->isTriggered()) {
					triggered[i] = true;
				}

				if (triggered[i]) {
					pads[i]->measureForce();
				}

				if (pads[i]->isMeasurementCplt()) {
					sprintf(dbg_buf, "-- Pad %s hit --\r\n", pads[i]->ID2Str(pads[i]->getID()));
					DBG(dbg_buf);

					ui.updatePadStats(pads[i]->getID(), 1);
					
					if (midi.isConnected()) {
						if (!midi.sendNoteOn(pads[i]->getID(), pads[i]->getForce(), 10)) {
							DBG("MIDI note sending failed!\r\n");
						} else {
							sprintf(dbg_buf, "MIDI Note On sent %d\r\n", pads[i]->getForce());
							DBG(dbg_buf);
							ui.updateMidiStats();
						}
					} else {
						DBG("MIDI not connected!\r\n");
						ui.updateMidiConn(false);
					}

					// This section is for pad insts upper_limit testing. Use MaxF value for reference.
					// Hit your pads (with large force) multiple times and record the maxF value.
					// This value differs because of sensor sensitivity, drumpad fastness, and adc sampling speed.
					// Then set the pad's upper_limit to a value slightly LESS than maxF.
					// //
					// sprintf(dbg_buf, "Pad %s MIDI force: %d\r\n", pads[i]->ID2Str(pads[i]->getID()), pads[i]->getForce());
					// DBG(dbg_buf);
					// static uint16_t maxF[Pad::PAD_NUM] = { 0 };
					// uint16_t peak_val = pads[i]->getPeak_DBG();
					// if (peak_val > maxF[i]) {
					// 	maxF[i] = peak_val;
					// }
					// sprintf(dbg_buf, "MaxF for %s: %d\r\n", pads[i]->ID2Str(pads[i]->getID()), maxF[i]);
					// DBG(dbg_buf);

					pads[i]->resetMeasurementCplt();
					triggered[i] = false;
				}
			}
		}

		// //Below is for ADC value waveform debugging.
		// //
		// uint16_t opHihat_val, clHihat_val, crash_val, ride_val, kick_val,
		//  		 snare_val, ssdk_val, htom_val, mtom_val, ltom_val;
		// opHihat_val = OpenHiHat.getADCVal_DBG();
		// clHihat_val = CloseHiHat.getADCVal_DBG();
		// crash_val = Crash.getADCVal_DBG();
		// ride_val = Ride.getADCVal_DBG();
		// kick_val = Kick.getADCVal_DBG();
		// snare_val = Snare.getADCVal_DBG();
		// ssdk_val = SideStick.getADCVal_DBG();
		// htom_val = HighTom.getADCVal_DBG();
		// mtom_val = MidTom.getADCVal_DBG();
		// ltom_val = LowTom.getADCVal_DBG();
		// sprintf(dbg_buf, "%d,%d,%d,%d,%d,%d,%d,%d,%d,%d\r\n",
		// 		opHihat_val, clHihat_val, crash_val, ride_val, kick_val,
		// 		snare_val, ssdk_val, htom_val, mtom_val, ltom_val);
		// DBG(dbg_buf);

		if (midi.isConnected()) {
			midi.autoNoteOff();
		}
		ui.updateMidiConn(midi.isConnected());

		// if (ui.isBuzzerEnabled()) {
		// 	__NOP();
		// }
		// if (ui.isLedEffectsEnabled()) {
		// 	__NOP();
		// }
		// if (ui.isDebugLogEnabled()) {
		// 	__NOP();
		// }

		// HAL_GPIO_TogglePin(LED_GPIO_Port, LED_Pin);  // This is for debugging, to see how fast the loop runs.
	}


	while (true); // Wait for death
}

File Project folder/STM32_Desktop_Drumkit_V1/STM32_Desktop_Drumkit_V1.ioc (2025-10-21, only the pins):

Mcu.UserName=STM32F405RGTx
PA0-WKUP.GPIO_Label=MT_ADC
PA0-WKUP.Signal=ADCx_IN0
PA1.GPIO_Label=LT_ADC
PA1.Signal=ADCx_IN1
PA10.Signal=USART1_RX
PA13.Signal=SYS_JTMS-SWDIO
PA14.Signal=SYS_JTCK-SWCLK
PA15.GPIO_Label=PWR_EN
PA15.Signal=GPIO_Output
PA2.Signal=USART2_TX
PA3.Signal=USART2_RX
PA4.GPIO_Label=OPENHIHAT_ADC
PA4.Signal=ADCx_IN4
PA5.GPIO_Label=CLOSEHIHAT_ADC
PA5.Signal=ADCx_IN5
PA6.GPIO_Label=CRASH_ADC
PA6.Signal=ADCx_IN6
PA7.GPIO_Label=RIDE_ADC
PA7.Signal=ADCx_IN7
PA8.GPIO_Label=RIDE_OUT
PA8.Signal=GPIO_Output
PA9.Signal=USART1_TX
PB11.GPIO_Label=SIDESTICK_OUT
PB11.Signal=GPIO_Output
PB12.GPIO_Label=KICK_OUT
PB12.Signal=GPIO_Output
PB13.GPIO_Label=SNARE_OUT
PB13.Signal=GPIO_Output
PB14.GPIO_Label=HT_OUT
PB14.Signal=GPIO_Output
PB15.GPIO_Label=MT_OUT
PB15.Signal=GPIO_Output
PB3.GPIO_Label=USB_RDY
PB3.Signal=GPIO_Input
PB4.GPIO_Label=CH345_ACK_IT
PB4.Signal=GPXTI4
PB6.Signal=I2C1_SCL
PB7.Signal=I2C1_SDA
PC0.GPIO_Label=SIDESTICK_ADC
PC0.Signal=ADCx_IN10
PC1.GPIO_Label=KICK_ADC
PC1.Signal=ADCx_IN11
PC10.GPIO_Label=KEY_PRESS
PC10.Signal=GPIO_Input
PC11.GPIO_Label=LED
PC11.Signal=GPIO_Output
PC12.GPIO_Label=BUZZER
PC12.Signal=GPIO_Output
PC2.GPIO_Label=SNARE_ADC
PC2.Signal=ADCx_IN12
PC3.GPIO_Label=HT_ADC
PC3.Signal=ADCx_IN13
PC6.GPIO_Label=LT_OUT
PC6.Signal=GPIO_Output
PC7.GPIO_Label=OPENHIHAT_OUT
PC7.Signal=GPIO_Output
PC8.GPIO_Label=CLOSEHIHAT_OUT
PC8.Signal=GPIO_Output
PC9.GPIO_Label=CRASH_OUT
PC9.Signal=GPIO_Output
PH0-OSC_IN.Signal=RCC_OSC_IN
PH1-OSC_OUT.Signal=RCC_OSC_OUT

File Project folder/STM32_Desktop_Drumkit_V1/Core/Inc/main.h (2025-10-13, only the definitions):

#define SIDESTICK_ADC_Pin GPIO_PIN_0
#define SIDESTICK_ADC_GPIO_Port GPIOC
#define KICK_ADC_Pin GPIO_PIN_1
#define KICK_ADC_GPIO_Port GPIOC
#define SNARE_ADC_Pin GPIO_PIN_2
#define SNARE_ADC_GPIO_Port GPIOC
#define HT_ADC_Pin GPIO_PIN_3
#define HT_ADC_GPIO_Port GPIOC
#define MT_ADC_Pin GPIO_PIN_0
#define MT_ADC_GPIO_Port GPIOA
#define LT_ADC_Pin GPIO_PIN_1
#define LT_ADC_GPIO_Port GPIOA
#define OPENHIHAT_ADC_Pin GPIO_PIN_4
#define OPENHIHAT_ADC_GPIO_Port GPIOA
#define CLOSEHIHAT_ADC_Pin GPIO_PIN_5
#define CLOSEHIHAT_ADC_GPIO_Port GPIOA
#define CRASH_ADC_Pin GPIO_PIN_6
#define CRASH_ADC_GPIO_Port GPIOA
#define RIDE_ADC_Pin GPIO_PIN_7
#define RIDE_ADC_GPIO_Port GPIOA
#define SIDESTICK_OUT_Pin GPIO_PIN_11
#define SIDESTICK_OUT_GPIO_Port GPIOB
#define KICK_OUT_Pin GPIO_PIN_12
#define KICK_OUT_GPIO_Port GPIOB
#define SNARE_OUT_Pin GPIO_PIN_13
#define SNARE_OUT_GPIO_Port GPIOB
#define HT_OUT_Pin GPIO_PIN_14
#define HT_OUT_GPIO_Port GPIOB
#define MT_OUT_Pin GPIO_PIN_15
#define MT_OUT_GPIO_Port GPIOB
#define LT_OUT_Pin GPIO_PIN_6
#define LT_OUT_GPIO_Port GPIOC
#define OPENHIHAT_OUT_Pin GPIO_PIN_7
#define OPENHIHAT_OUT_GPIO_Port GPIOC
#define CLOSEHIHAT_OUT_Pin GPIO_PIN_8
#define CLOSEHIHAT_OUT_GPIO_Port GPIOC
#define CRASH_OUT_Pin GPIO_PIN_9
#define CRASH_OUT_GPIO_Port GPIOC
#define RIDE_OUT_Pin GPIO_PIN_8
#define RIDE_OUT_GPIO_Port GPIOA
#define PWR_EN_Pin GPIO_PIN_15
#define PWR_EN_GPIO_Port GPIOA
#define KEY_PRESS_Pin GPIO_PIN_10
#define KEY_PRESS_GPIO_Port GPIOC
#define LED_Pin GPIO_PIN_11
#define LED_GPIO_Port GPIOC
#define BUZZER_Pin GPIO_PIN_12
#define BUZZER_GPIO_Port GPIOC
#define USB_RDY_Pin GPIO_PIN_3
#define USB_RDY_GPIO_Port GPIOB
#define CH345_ACK_IT_Pin GPIO_PIN_4
#define CH345_ACK_IT_GPIO_Port GPIOB
#define CH345_ACK_IT_EXTI_IRQn EXTI4_IRQn

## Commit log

2025-10-13 Uploaded Hardware Related files
    [Drumkit Cover.SLDPRT, DrumpadFastener Crash 74.SLDPRT, DrumpadFastener Hi_Mid_Tom 56.SLDPRT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]
2025-10-13 Added step 3D files
    [Drumkit Cover.3mf, Drumkit Cover.STEP, DrumpadFastener Crash 74.STEP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]
2025-10-14 Added PCB BOM Table and modified readme
    [BOM_PCB_MotherBrd.xlsx, BOM_PCB_UI.xlsx]
2025-10-14 Updated 3D Printing descriptions
2025-10-14 Updated assembling guide
2025-10-14 Added assembly guide
2025-10-21 Added UI::Buzzer class support
    [STM32_Desktop_Drumkit_V1.ioc, config.h, cpp_main.cpp]
2025-10-25 Added a low velocity forbid configuration
2026-04-04 Update README with project details and repository link
    Added project link and overview for STM32 Desktop Drumkit.

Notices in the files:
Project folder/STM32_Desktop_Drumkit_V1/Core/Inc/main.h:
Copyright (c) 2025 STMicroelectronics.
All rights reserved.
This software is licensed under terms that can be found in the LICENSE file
